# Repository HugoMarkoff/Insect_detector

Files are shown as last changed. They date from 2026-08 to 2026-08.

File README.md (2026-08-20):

# 🐞 Project Mariehøne

*“Mariehøne” is Danish for ladybug — which is exactly what the enclosure is.*





A wildlife-trap PCB repurposed into an **insect timelapse camera**, with a live
public gallery. An ATmega328P controller drives an infrared illuminator and a
Raspberry Pi + NoIR camera to take a frame every few minutes — no motion
trigger, just steady frames, day and night.

### ▶ Live gallery: **https://hugomarkoff.github.io/project-mariehoene/**

Built on the **Animal Detect Trap PCB V3.3** — ATmega328P +
Raspberry Pi + IMX708 NoIR camera, reverse-engineered from the Altium project
and the original Animal Detect firmware.

---

## What's here

| Path | What it is |
|---|---|
| **[docs/FLASHING.md](docs/FLASHING.md)** | **How to flash a board** — the two-stage procedure (one-time bootloader burn over ISP, then serial uploads), with a photo of exactly which pins to hold |
| [docs/HARDWARE.md](docs/HARDWARE.md) | Board reference: every connector pinout, the MCU pin map, power architecture, and the full I2C command table |
| [docs/RPI.md](docs/RPI.md) | The Raspberry Pi side: timelapse capture, the live web gallery, and how it publishes to GitHub Pages |
| [firmware/](firmware/) | PlatformIO project — the ATmega328P timelapse firmware (v0.2) |
| [programmer/](programmer/) | Turn a working board into an ISP programmer (ArduinoISP) + a retry-until-it-works bootloader burner |
| [rpi/](rpi/) | Raspberry Pi scripts: `timelapse.py` (capture + gallery), `gh_uploader.py` (push to GitHub), systemd units |
| [web/](web/) | The GitHub Pages gallery front-end (`index.html`) |

---

## How it works

The board can run in two modes; the firmware supports both.

**1. WiFi timelapse (what's deployed here)** — the Raspberry Pi stays powered and
runs the show:

```
Raspberry Pi (always on, WiFi)                 ATmega328P (I2C slave @0x08)
  every 3 min:                                   ┌───────────────────────┐
  ├─ I2C: IR on  (0x0F) ───────────────────────► │ drives IR illuminator │
  ├─ capture frame (NoIR camera)                 │ reads battery / light │
  ├─ I2C: IR off (0x0F) ───────────────────────► │ level-shifted 5V↔3V3  │
  ├─ save + serve local gallery (:8080)          └───────────────────────┘
  └─ git push rolling window ─► GitHub ─► Pages ─► public gallery
```

**2. Battery trap (low-power)** — the ATmega328P is the scheduler: it power-gates
the Pi, wakes it on an interval (or PIR/reed), lets it capture, then cuts power
and sleeps. Set always-on (`0x0E`) to keep the Pi up, or let it cycle to save
battery. See the command table in [docs/HARDWARE.md](docs/HARDWARE.md).

> ⚡ **On battery the Pi's 5 V is gated by the Arduino**, so without an always-on
> command the firmware will power-cycle the Pi every ~80 s by design. [docs/RPI.md](docs/RPI.md)
> explains the always-on setup that keeps it running for the WiFi timelapse.

---

## Quick start

1. **Flash the board** → [docs/FLASHING.md](docs/FLASHING.md). A fresh chip needs a
   one-time bootloader burn over ISP; after that it takes normal serial uploads.
2. **Build & upload the firmware:**
   ```bash
   cd firmware
   pio run -e Upload_UART -t upload      # over the Boot1 serial header
   ```
3. **Set up the Raspberry Pi** — clone this repo on the Pi and run the installer:
   ```bash
   cd project-mariehoene/rpi && GH_USER=<you> ./setup.sh
   ```
   It installs the capture loop, local gallery, and GitHub Pages publisher as
   systemd services, and walks you through the deploy key. Details in
   [docs/RPI.md](docs/RPI.md).
4. **Watch it** at your Pages URL, or locally at `http://<pi-ip>:8080/`.

Tuning (all in [firmware/src/main.cpp](firmware/src/main.cpp) or at runtime over I2C):

- Interval: `#define DEFAULT_INTERVAL_SECONDS`, or I2C `0x0D` (2 bytes of seconds).
- Quiet window: I2C `0x06` (from/to h,m,s) — skip captures at night.
- Bench testing without a battery: `#define ENABLE_BATTERY_GUARD 0` (a floating
  A0 reads garbage and would otherwise sleep the MCU forever).

---

## Hardware

Animal Detect Trap PCB V3.3 · ATmega328P @ 16 MHz · Raspberry Pi · IMX708 NoIR
camera · IR illuminator · 2S Li-ion. The board carries connectors for PIR, reed
(MAG), an IR/flash output, a spare trigger output, an LDR (dusk sensing), and a
`Boot1` serial header for programming. Full pinout in [docs/HARDWARE.md](docs/HARDWARE.md).

## Contributing

Issues and PRs welcome — see [CONTRIBUTING.md](CONTRIBUTING.md). Ideas and open
improvements are tracked in [docs/IMPROVEMENTS.md](docs/IMPROVEMENTS.md).

## License

[MIT](LICENSE) © 2026 Hugo Markoff.

## Credits

Derived from the Animal Detect trap platform. Firmware and the
RPi stack rewritten here for standalone insect timelapse use (no cloud backend —
images publish straight to GitHub Pages).

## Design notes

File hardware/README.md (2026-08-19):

# Open hardware — Animal Detect camera-trap family 🔓

The PCB designs and production 3D-print files behind the Really a Robot /
Animal Detect camera trap — the same hardware the [insect detector](../README.md)
is built from. Released open source under the repository's MIT license
(if you build or remix, a mention is appreciated).

## PCBs (Altium)

| Board | Newest ★ | Folder | What's inside |
|---|---|---|---|
| **IR array** (batwing illuminator) | v6.1 | `pcb/ir-array/` | v5 complete project (PrjPcb + SchDoc — the only schematic), v6 + **v6.1 ★** PcbDocs |
| **Main trap PCB** (ATmega328P host for a Pi Zero) | SMT2024 SMD-v3 | `pcb/trap-main/` | **SMD-v3 ★** complete project, early apr02 respin, v3.3 project + `full-archive-with-history.zip` (10 design snapshots V2→V3.2 **including manufacturing gerbers**) + `v3-docs/Trap_PCB_V3.pdf` |
| **PIR module** | v1.0 | `pcb/pir/` | PcbDoc + SchDoc |

Key dimensions, parsed straight from the PcbDocs:

| Board | Size | Mount holes |
|---|---|---|
| IR array v6.1 | 81.0 × 98.4 mm batwing, camera slot 37.2 wide | 2 × Ø3.0 on the centreline at (0,−6.5), (0,−29.1) |
| Main trap SMT2024 | 82.0 × 40.0 mm | 4 × Ø2.8 in a 58 × 23 pattern (= Pi Zero pattern — the Pi stacks on) |
| PIR v1.0 | 40.2 × 20.5 mm | 3 × Ø2.2 triangle: (−15, ±10) and (+15, 0) |

The magnet input is a bare reed switch on the trap PCB's MAG line — it never
had its own board.

## Camera-trap 3D parts (`cad/`)

The complete production print set (3MF), 30 files:

| Group | Parts |
|---|---|
| Enclosure | `Front-shell`, `Back-shell`, `Cam-Insert`, `IR-Insert-Folding`, `Bracket` |
| Battery | `Battery_Top`, `Battery_Buttom`, `Battery-Knob`, `BattPCB-Bracket` |
| Charger | `Charger-Top`, `Charger-buttom`, `Charger-IconInlay` |
| PIR | `PIRbracket`, `PIR-Funnel` (+ `TEST/New-PIR/` variants) |
| Antenna | `AntennaSafe`, `AntennaSafeInsert`, `AntennaSafeTip` |
| Mounting | `TreeBracket`, `Tree-Knob`, `Shade`, `Shade - Big` |
| `TEST/` | print-tuning coupons (`M3-test`, `PET-G_Test`, shell/PIR variants) |

`Cam-Insert` is worth a look even if you build nothing else: it encodes the
camera ↔ pogo-interface-board stack (camera in a 1.2 mm pocket, second board
7.4 mm seat-to-seat above it) that the insect detector's ladybug belly reuses.

## Bill of materials & docs (`docs/`, `pcb/trap-main/v3-docs/`)

| File | What |
|---|---|
| `docs/AD_BOM_list.xlsx` | AD camera bill of materials |
| `docs/Trap_v4_BOM.xls` | Trap v4 bill of materials |
| `pcb/trap-main/v3-docs/Trap_PCB_V3.pdf` | Trap PCB V3 documentation |
| `pcb/trap-main/v3-docs/Schematic_V3.jpg` | Trap V3 schematic (image) |
| `pcb/trap-main/v3-docs/i2c-Pogo-diagram-V2.jpg` | The I2C **pogo-pin interface** diagram |

## Legacy firmware & code

- `firmware-legacy/` — the original Arduino bring-up sketches: battery
  capacity (Li-Ion + NiMH), I2C tests, latch/battery-status tests.
- `legacy-camera-code/` — full snapshot of the original Bitbucket repo
  (`rmd_rar`): trap-PCB PlatformIO firmware + Raspberry Pi capture/upload
  scripts. **All credentials stripped** — see `LEGACY-NOTE.md` inside.

## Related

- The **ladybug insect-camera enclosure** (parametric FreeCAD) lives on the
  `main` branch under [`enclosure/`](../../tree/main/enclosure).
- Firmware for the trap PCB + Raspberry Pi timelapse/upload scripts:
  [`firmware/`](../../tree/main/firmware) and [`rpi/`](../../tree/main/rpi)
  on `main`.

## Notes

- Altium files are binary; folders are organised **one version per folder**
  so history stays browsable without Altium.
- No keys, credentials, or customer data are contained in any of these files.

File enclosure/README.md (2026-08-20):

# Ladybug enclosure 🐞 — v1.2

**v1.2:** ~20 % more floor area (body 142 × 188) and a properly hollow shell
(walls 3.0 / 2.6 mm) — real storage room under the dome. Every hardware mount
sits at the same coordinates as v1.1, so boards swap straight over.

A 3D-printed ladybug that hides the electronics under its shell and looks
**straight down** at whatever it's standing over. Legs are Lego-style stacking
blocks, so the same body works at 2 cm or 15 cm off the ground.

**Part 1 (here): the belly** — [`ladybug_belly.py`](ladybug_belly.py), a
parametric FreeCAD script. [`make_drawing.py`](make_drawing.py) generates a
dimensioned top/bottom drawing from the same parameters.
**Part 2 (also here): the domed elytra shell** — `build_shell()` in the same
script, so the seal dimensions can never drift apart.

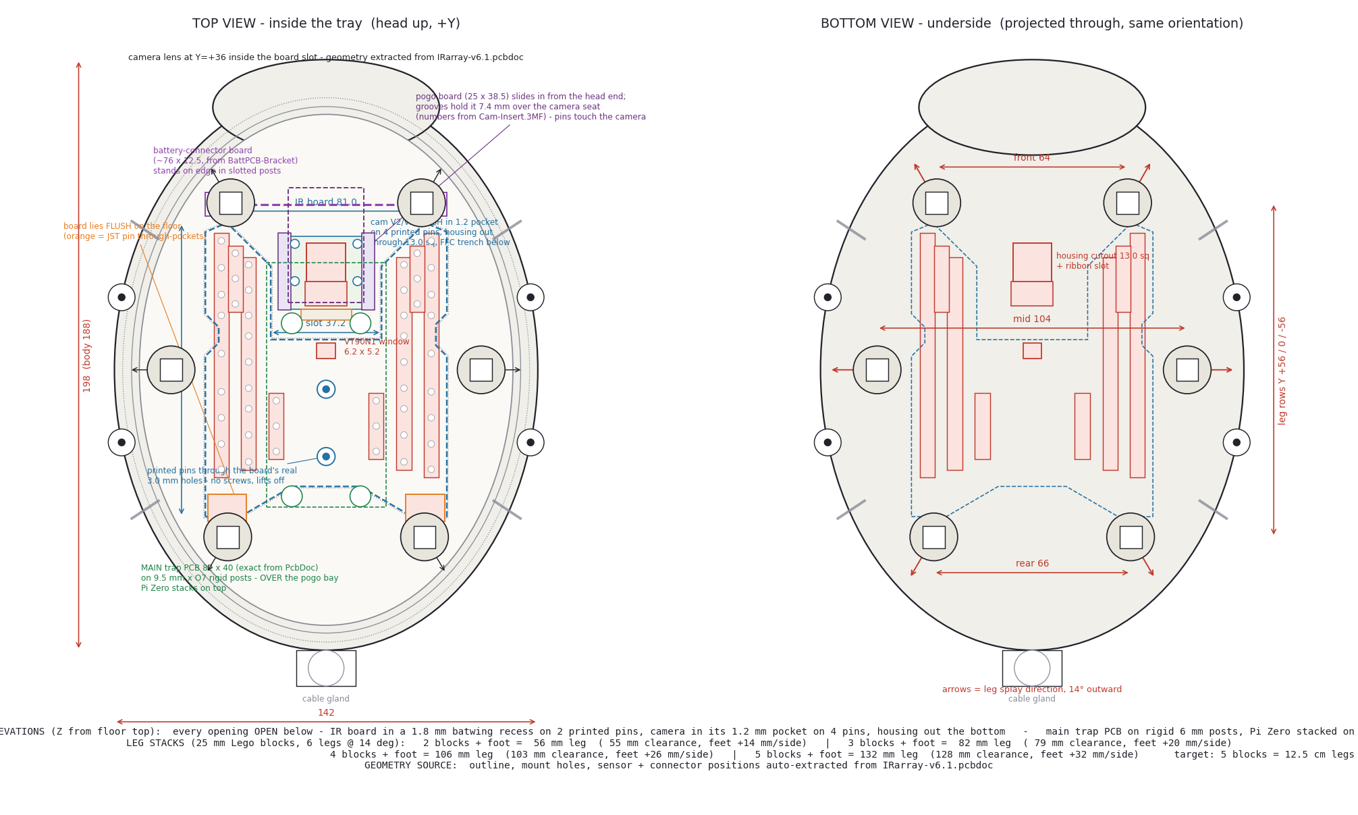
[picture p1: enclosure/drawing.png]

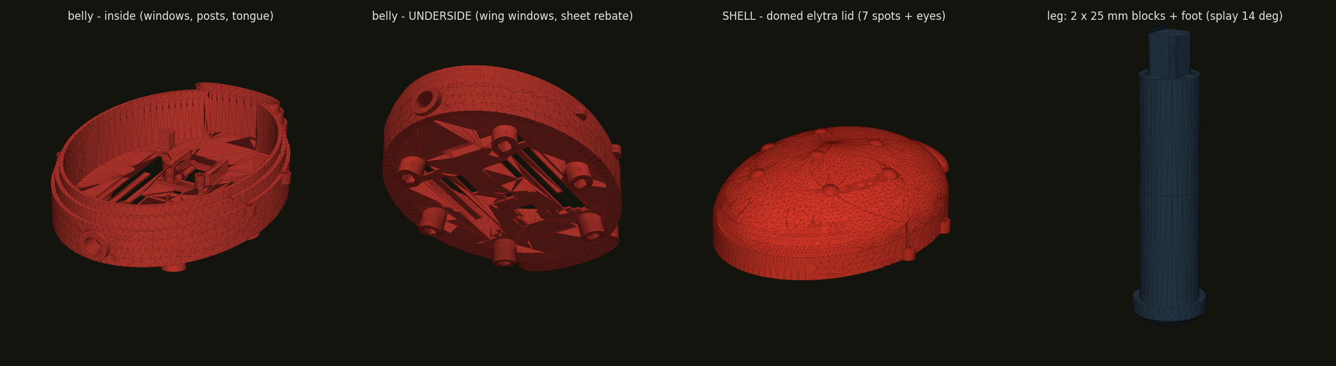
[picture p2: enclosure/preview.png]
preview


The IR board's geometry was pulled **straight out of the Altium file** (see
[`irboard_extracted.png`](irboard_extracted.png)) — outline, mount holes,
sensor and connector positions are manufacturing-exact.

## How the real hardware mounts

Everything lives **inside** the body. Measured off the actual boards:

| Part | Where it goes | How |
|---|---|---|
| **IR board** (batwing X, 81 × 98.4 — exact from the PcbDoc) | Drops into a **1.8 mm batwing recess** (~1 mm slack) onto **two printed pins** through its real holes (0,−6.5)/(0,−29.1) — no screws, lifts straight off | The floor has **one slot per LED column** (sized to the exact 48 LED positions from the PcbDoc; touching columns merge) — only the diode zones and the light sensor are open. The centre strip (logo, mount holes, the JST pins, the sensor legs) stays over solid floor, and the board **seals its own opening**: LEDs drop into the windows, the sensor into its hole, the JST pin fields into through-pockets. Silicone/foam on the strip makes it airtight |
| **Light sensor** (VT90N1 at (0,+6.3) — from the PcbDoc) | Its own **rectangular window (6.2 × 5.2)** matching the CdS cell's body | Reads ambient light straight down |
| **Camera** (Pi V2 **or** V3 — same 25 × 24 board, 21 × 12.5 holes) | **Flush in a 1.2 mm floor pocket** inside the board slot, located by **four printed pins** (Ø1.8 in its 2.2 mm holes) | Only the **sensor housing pokes out** through a 13 mm square cutout (passes the bulky Module 3 housing), with a wide offset slot that swallows both the V3 ribbon and V2's L-shaped flex; a shallow trench lets the main FFC cable lie flat. Above it, **slide-in rails carry the pogo interface board** (25 × 38.5) exactly 7.4 mm over the camera seat — spacing decoded from `Cam-Insert.3MF` — so the pogo pins land on the camera's back |
| **Main trap PCB** (82 × 40, holes 58 × 23 — exact from its PcbDoc) | Across the body on rigid 9.5 mm × Ø7 posts, riding just above the pogo board | Upper posts stand in the camera slot, lower ones below the board's bottom edge; the **Pi Zero stacks onto the trap PCB's own 58 × 23 pattern** |

> **Sealing:** there is **no window sheet** — every opening is filled by the
> component that uses it, and the boards clamped flush **are** the seal. The
> openings face the ground, so rain can't fall in. Conformal-coat the IR
> board's LED face (or spray it with clear lacquer) for damp nights.

The board keeps **~1.5–6 mm wiggle room** to the cavity wall all the way round —
it drops in flat and lifts out without a fight.

## Build it

FreeCAD 1.0+ (free). Either open the script in FreeCAD's Python console, or run
it headless — it writes STLs into `stl/` and a `ladybug.FCStd` you can open and
edit:

```bash
"C:\Program Files\FreeCAD 1.0\bin\FreeCADCmd.exe" ladybug_belly.py
```

It prints a check per part; every one must say `printable=True` (a single closed
solid). Current output:

Every run builds **both size options** — same features, shared legs:

| Part | v1.1 (1:1 original) | v1.2 (+20% floor) |
|---|---|---|
| `belly` | 135 × 185 × 54 mm, ~174 cm³ → `stl/v1.1/` | 146 × 201 × 54 mm, ~195 cm³ → `stl/v1.2/` |
| `shell` | 136 × 186 × 59 mm, ~137 cm³ → `stl/v1.1/` | 148 × 202 × 59 mm, ~154 cm³ → `stl/v1.2/` |

Both shells are the hollow thin-wall design; legs below fit either body.

| Shared part | Size | Volume |
|---|---|---|
| `leg_segment` | Ø13 × 35 mm (25 body + 10 peg) | 3.1 cm³ |
| `leg_segment_half` | Ø13 × 22.5 mm | 1.5 cm³ |
| `foot` | Ø16 collar + ball, 16.5 mm | 1.4 cm³ |

## The waterproof lid ("lift") — how the seal works

The shell is a **lid that lifts straight off**. Water never gets a straight path
in, because the joint is a labyrinth:

```
        shell skirt (part 2)
          |  ||                  skirt hangs OUTSIDE, down over the rebate
          |  ||   __ tongue      belly tongue rises INSIDE the skirt,
          |  ||  |  |            into a matching groove in the shell
       ___|  ||__|  |___         seat + gutter, with weep notches
      |      belly       |
       \__ shoulder: skirt edge stops here, water drips off __/
```

- Rain runs down the shell and **drips off the skirt's bottom edge** at the
  shoulder — below and outside the joint.
- To get in, water would have to climb **8 mm up a gap and over a 6 mm tongue**.
  It can't; gravity is on our side.
- Any splash that does land in the gutter drains out through the **weep
  notches** cut in the top of the rebate wall.
- The **screw ears are outside the seal**, so the fixings can't leak.
- The **leg sockets are blind** — they open downward only and never break
  through the floor into the dry side.

Two things you still add by hand:

1. **The gasket.** Run a thin bead of silicone (or lay 1 mm foam tape) on
   the floor's centre strip and around the camera pocket before pressing the
   boards down — PCB on plastic is weather-resistant, silicone makes it
   airtight (and still peels open for service).
2. **A vent.** A fully sealed box breathes with temperature and sucks moisture
   past any seal. Stick a small square of PTFE/Gore vent tape over a 3 mm hole
   drilled high on a side wall, or accept the (slightly leaky) cable gland as
   your vent.

## Printing

| Part | Qty | Notes |
|---|---|---|
| `belly` | 1 | Print as-is, belly down. The leg bosses are the only overhang and they're short — no supports needed. |
| `shell` | 1 | Print as modelled (skirt ring down). The dome is self-supporting; the groove bridges are ~3 mm — fine. Red filament, black spots with a marker (or pause-and-swap). |
| `leg_segment` | 30 (6 legs × 5) | 25 mm each — 5 per leg ≈ 12.5 cm legs. |
| `leg_segment_half` | 4–8 | 12.5 mm fine-adjust blocks for slopes. |
| `foot` | 6 | Print peg-up. |

0.2 mm layers, 3 perimeters, 20–30 % infill. **PETG or ASA if it lives
outdoors** — PLA sags in a sun-baked enclosure. TPU feet grip better and damp
vibration.

> **Print one `leg_segment` + one `foot` first** and check the peg grip. Too
> loose → lower `fit` (0.15–0.2). Too tight → raise it (0.4–0.5). Printer
> tolerance varies more than the model does; this one number is the whole trick.

## Height adjustment (the Lego bit)

**Six legs — front, middle and rear pairs — tilted 14° outward** like a
tripod. The system is LEGO-simple: **round parts outside (Ø13 blocks, Ø16
belly bosses, Ø16 ball feet), ONE standard square hole inside** — a straight
7.15 mm peg in a 7.45 mm rounded-corner socket — 0.3 mm of wiggle: drops
together by hand, no slop. (The peg also fits bellies printed with the older
7.4 sockets, at 0.25 play.) The foot's top is a straight collar at exactly
`socket_od`, so the joint reads as one continuous column — if your printed
belly's bosses measure differently, set `socket_od` and reprint only the feet. 10 mm engagement + blocks butting face-to-face keep tall stacks
stiff instead of wobbling up. The belly sockets are angled,
so the taller you stack, the wider the stance. Every `leg_segment` adds **25 mm**
along the leg:

```
belly socket (14° out) → [block] → [block] → ... → [foot]
```

| Blocks per leg | Leg length | Ground clearance | Feet spread |
|---|---|---|---|
| 2 | 56 mm | 54 mm | +14 mm/side |
| 3 | 81 mm | 79 mm | +20 mm/side |
| 4 | 106 mm | 103 mm | +26 mm/side |
| **5** | **131 mm ≈ 12.5 cm** | **127 mm** | **+32 mm/side** |

- **Square pegs** mean the legs can't rotate — the splay angle stays put.
- **Why 14°?** The camera sees ~62° × 49°, so no sane splay keeps legs out
  of the extreme corners at every height — 14° keeps the upper leg sections
  (the close, blurry, dominant ones) out of view at working heights without
  making the stance silly. If you build very tall and the corners bother you,
  raise `leg_splay` a few degrees and reprint just the belly.
- Stack the downhill legs taller (use the half blocks) to stand level on a slope.

**Camera height is your focus knob.** The IMX708 won't focus closer than ~10 cm,
so print enough segments to bracket 10–20 cm.

## Fitting your hardware

Everything is in the `PARAMS` block at the top of the script — change a number,
re-run. The ones you'll actually touch:

| Param | What it does |
|---|---|
| `body_len`, `body_wid` | Overall footprint |
| `ir_outline` | The exact batwing outline (auto-extracted from `IRarray-v6.1.pcbdoc`) |
| `ir_mounts`, `sensor_pos` | Exact centreline holes + VT90N1 spot (from the PcbDoc) |
| `win_inset`, `win_xmin` | Wing-window fit: rim width and solid-strip width |
| `cam_pos`, `cam_lens_d` | Camera lens hole (Ø12 clears V2 and V3) |
| `cam_cut_sq`, `cam_fit` | Camera housing cutout + pocket tightness |
| `main_posts`, `main_post_h` | Trap-PCB standoffs (58 × 23 pattern, from its PcbDoc) |
| `leg_splay`, `leg_seg_h` | Tripod angle and block height |
| `fit` | Leg peg tightness |
| `skirt_th`, `skirt_gap`, `tongue_w`, `tongue_h` | The seal — part 2 must match these |

> ⚠️ Before printing the belly, measure and set: `ir_mounts` (the two
> centreline holes), `sensor_pos`, and check the notch/outline against your
> PCB. Everything else is dimensioned from the real hardware.
> The legs are safe to print right now.

### Internal layout (bottom → top)

| Z from floor top | What |
|---|---|
| 0–3 mm | Floor, with wing windows + sensor + lens holes; clear sheet in the rebate below |
| 3 mm | Camera posts — lens reaches down into its hole, baffle collar around it |
| below 0 | Camera **sensor housing pokes out** (V2 ~2.5 mm, V3 ~5 mm); LED domes sit just inside their windows |
| 0–3 mm | Floor — **IR board and camera both recessed flush on printed pins**, sealing their own openings |
| 13 mm | **Main trap PCB** on 10 mm posts; the Pi Zero stacks onto it above |
| 33 mm | Seat level — the shell's skirt lands here |

## Still to design

- [x] The domed **elytra shell** — seven-spot dome with eye bumps, skirt +
      groove matched to the belly, four M3 tabs over the belly ears.
      (The centre split line defeated the CAD kernel — draw it with a marker.)
- [ ] Lens hood / dew shield around the camera port.
- [ ] Head with the "eyes" as vent detail.

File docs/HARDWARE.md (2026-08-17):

# Trap PCB V3.3 — hardware reference

Reverse-engineered from `Trap_PCB_V3.3.SchDoc` (net-traced programmatically) and
the assembled board. Note: the schematic in the project folder lags the fabbed
V3.3 in component *packages* (it draws a DIP ATmega328-PU and an LM2576 buck;
the board carries a TQFP-32 MEGA328P-AU and an RT7272B buck) — but the **net
topology matches the firmware pin usage exactly**, so the pinouts below are the
fabbed board's.

## Power

- `VIN` JST (2-pin): 2S battery, ~6.0–8.8 V. Reverse diodes 1N5406, big input electrolytic.
- Buck regulator → **5.1 V rail**: MCU (AVCC/AREF too — that's why the firmware
  uses `analogReference(EXTERNAL)` with 5.0 as reference constant), sensors, and
  the switched RPi supply.
- Battery sense: A0 through 30K/7K5 divider (matches `R1=30000, R2=7500` in firmware).
- RPi power is **high-side switched by an IRLZ44N** driven from `A2-GATE`
  (Arduino pin 16 / A2, `RELAY_PIN` in firmware). Two more IRLZ44Ns low-side
  switch the `Trig` and `IR` JST loads (gates on D4 / D5).

## MCU pin map (ATmega328P, Arduino numbering)

| Arduino | Net | Function |
|---|---|---|
| D0/D1 | RX / TX | Serial: debug + urclock upload (Boot1 header) |
| D2 | D2-PIR | PIR signal (INT0) |
| D3 | D3-MAG | Reed/magnet sensor (INT1) |
| D4 | D4-Trig | Low-side switch for `Trig` JST |
| D5 | D5-IR | Low-side switch for `IR` JST (IR flash board) |
| D10 | CS | Digipot chip-select (digipot sits on the PIR sensor board) |
| D11 (MOSI) | SI | Digipot data — also on PIR connector pin 6 |
| D12 (MISO) | MISO | **Chip leg only — no connector.** Needed for ISP |
| D13 (SCK) | SCK + D13-LED | Digipot clock, PIR pin 5, onboard LED (220R) |
| A0 | A0-BATT | Battery divider |
| A1 | A1-LDR | Photoresistor (`LDR` JST) — dusk detection for IR flash |
| A2 (D16) | A2-GATE | RPi power gate (firmware `RELAY_PIN`) |
| A4/A5 | SDA/SCL | I2C slave @ 0x08 to the RPi, level-shifted by 2N7000 pair |
| RESET | Reset | 10K pull-up, RST button to GND, 100 nF from Boot1 DTR |
| XTAL | Crystal1/2 | 16 MHz + 22 pF |

## Connectors

### Boot1 — programming/serial header (6-pin 2.5 mm female, bottom-right)

| Pin | Net |
|---|---|
| 1 | DTR (cap-coupled to RESET) |
| 2 | TX |
| 3 | RX |
| 4 | 5.1V |
| 5 | GND |
| 6 | NC |

### PIR Sensor (JST-PH 2.0 mm, 6-pin)

| Pin | Net | Note |
|---|---|---|
| 1 | 5.1V | |
| 2 | GND | |
| 3 | D2-PIR | Motion signal |
| 4 | CS | Digipot (sensitivity) on sensor board |
| 5 | SCK | **ISP tap point** |
| 6 | SI (=MOSI) | **ISP tap point** |

### Small JSTs

| Conn | Pin 1 | Pin 2 |
|---|---|---|
| VIN | Battery + (VIN net) | GND |
| Trig | 5.1V | switched drain (low-side FET, D4) |
| IR | 5.1V | switched drain (low-side FET, D5) |
| LDR | A1 divider | (photoresistor) |
| MAG | GND / 5V / SIG(D3) | 3-wire sensor |

### Pogo pins P1–P7 (press onto the RPi Zero 2 W header holes 1–6 + GND)

| Pogo | Net | RPi header pin |
|---|---|---|
| P4 | POGO-3V | 1 (3V3 — used only as level-shifter reference) |
| P1, P2 | 5.1V (switched) | 2, 4 (5V in) |
| P5 | POGO-SDA | 3 |
| P6 | POGO-SCL | 5 |
| P3, P7 | POGO-GND | 6, 9 |

The 2N7000 pair shifts SDA/SCL between the AVR's 5 V and the RPi's 3.3 V using
POGO-3V as the low-side pull-up rail — the classic bidirectional MOSFET shifter.

## I2C protocol (Arduino = slave @ 0x08, firmware v0.2)

**Writes** (`i2cset -y 1 0x08 CMD data…`):

| Cmd | Payload | Meaning |
|---|---|---|
| 0x00 | s, m, h | Sync wall clock |
| 0x04 | hours | Ping interval |
| 0x05 | h, m, s | Ping time |
| 0x06 | from h,m,s + to h,m,s | Quiet window (no captures inside it) |
| 0x08 | seconds | IR flash on (respects dusk value) |
| 0x09 | value/4 | Dusk threshold |
| 0x0B | 1–254 | PIR sensitivity (digipot) |
| 0x0C | minutes (254=default) | Capture interval, coarse |
| 0x0D | hi, lo (seconds, ≥15) | **Capture interval in seconds** |
| 0x0E | 0/1 | **Always-on: 1 = never cut RPi power on timeout** |
| 0x0F | pin, state | **Direct output write: 0=IR, 1=Trig, 2=RPi gate** |
| 0x15 | seconds (10–255) | RPi on-time budget per cycle (default 80) |

**Reads** (`i2cset -y 1 0x08 CMD` then `i2cget -y 1 0x08`, or smbus write+read):

| Cmd | Returns |
|---|---|
| 0x01 | Setup status (0 = fresh boot, wants full config) |
| 0x02 | Battery % |
| 0x03 | Trigger reason: 1 PIR, 2 ping, 3 reed, **4 timelapse** |
| 0x07 | (Request shutdown — Arduino cuts RPi power after this) |
| 0x0A | Image type (0 RGB, 1 IR) |
| 0x10 | **PIR input level** |
| 0x11 | **Reed/MAG input level** |
| 0x12 | **LDR reading /4 (0–255)** |
| 0x13 | **Battery voltage in decivolts (74 = 7.4 V)** |
| 0x14 | **Firmware version (2)** |

Cadence math: the capture schedule anchors at cycle start —
`next = cycle_start + interval` — so RPi boot/capture/shutdown time is absorbed
into the sleep and shot-to-shot spacing equals the configured interval exactly
(as long as interval > cycle time, i.e. ≥ ~60 s intervals are safe with a 45 s cycle).

Always-on: send `0x0E 0x01` at boot and simply never send `0x07` — the Arduino
freezes its timeout clock and leaves power up indefinitely. An explicit `0x07`
still shuts down even in always-on. Direct gate control (`0x0F 0x02 0x00`)
cuts your own power — that's the intended way for the RPi to hard-poweroff
outside the normal handshake (run `sudo poweroff` first, gate off ~10 s later
via a shutdown service, or just let cmd 0x07 handle it).

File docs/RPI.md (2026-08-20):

# Raspberry Pi setup — capture, gallery & publishing

The Pi runs three moving parts, all as systemd services so they survive reboots
(important on battery, where the board can brown-out and restart):

1. **`timelapse.py`** — captures a frame every N seconds, drives the IR output on
   the Arduino around each shot, and serves a live local gallery on `:8080`.
2. **`gh_uploader.py`** — pushes the newest frames to GitHub as a rolling window.
3. **GitHub Pages** — serves the public gallery from the pushed images.

```
timelapse.py ──► ~/timelapse_images/*.jpg ──► gh_uploader.py ──► GitHub (images branch)
      │                                                                    │
   :8080 local gallery                          gh-pages branch (index.html) + GitHub Pages
                                                                           │
                                                          public gallery (auto-refreshes)
```

## Files

| File | Role |
|---|---|
| [rpi/timelapse.py](../rpi/timelapse.py) | Capture loop + local web gallery |
| [rpi/gh_uploader.py](../rpi/gh_uploader.py) | Rolling-window push to GitHub over an SSH deploy key |
| [rpi/insect-timelapse.service](../rpi/insect-timelapse.service) | systemd unit for capture (sets Arduino always-on on start) |
| [rpi/insect-uploader.service](../rpi/insect-uploader.service) | systemd unit for the GitHub push |
| [rpi/rc.local](../rpi/rc.local) | Neutralised boot script (replaces the old Firebase autostart) |
| [web/index.html](../web/index.html) | The Pages front-end (lists images via the GitHub API) |

## Capture (`timelapse.py`)

Configurable entirely by environment variables (set in the service unit):

| Env | Default | Meaning |
|---|---|---|
| `TIMELAPSE_INTERVAL` | `180` | Seconds between captures |
| `TIMELAPSE_IR_HOLD` | `0` | `1` = force the IR output on continuously (hardware test) |
| `TIMELAPSE_DIR` | `~/timelapse_images` | Where frames are written |

Each cycle: assert IR on (I2C `0x0F`), capture with `rpicam-still` (NoIR tuning),
IR off, save a timestamped JPEG, sleep to the next slot. It also sends the
Arduino **always-on** (`0x0E`) on startup so the board doesn't power-cycle the Pi.

Browse the raw feed locally at `http://<pi-ip>:8080/`.

## Insect detection (`detect.py`)

Each new frame is compared to the previous one (downscaled, blurred grayscale
absolute difference). A small, **localized** change means something appeared on
the otherwise-static scene — flagged as a likely insect. A near-zero change is an
empty frame; a huge change is a light/camera shift and is ignored. Thresholds are
env-tunable (`DETECT_DIFF`, `DETECT_MIN_FRAC`, `DETECT_MAX_FRAC`). It's a motion
proxy, not an ML classifier (see [IMPROVEMENTS.md](IMPROVEMENTS.md)); needs Pillow.

## Publishing (`gh_uploader.py`)

Keeps only the last `GH_KEEP` (default 60) images and **force-pushes a single
squashed commit** to the `images` branch — so repo history never grows and the
Pages branch is never rebuilt. It also writes **`manifest.json`** (each frame +
its insect flag/score, newest-first), which the gallery reads as its single data
source — one request per refresh instead of a directory crawl. The gallery shows
a **timelapse player** (plays frames across time), the **last 10 frames**, and the
**last 10 flagged with insects**.

Auth is an **SSH deploy key** scoped to this one repo (`~/.ssh/insectcam_deploy`),
not a token. The repo must be **public** for anonymous visitors' browsers to read
the image list.

## First-time setup

**The easy way** — clone the repo on the Pi and run the installer, which does
everything below (deps, deploy key, gh-pages, services) and only asks you to
paste one public key:

```bash
cd project-mariehoene/rpi && GH_USER=<your-github-user> ./setup.sh
```

<details><summary>Or do it manually</summary>

```bash
# 1. Dependencies
sudo apt-get update && sudo apt-get install -y git python3-smbus2   # (smbus2 via pip if unavailable)

# 2. Deploy key (grant the Pi push access to just this repo)
ssh-keygen -t ed25519 -N '' -f ~/.ssh/insectcam_deploy -C insectcam-pi
cat ~/.ssh/insectcam_deploy.pub
#   → add at github.com/<you>/project-mariehoene/settings/keys  (✅ Allow write access)

# 3. Copy scripts to ~/ , then install the services
sudo cp insect-timelapse.service insect-uploader.service /etc/systemd/system/
sudo cp rc.local /etc/rc.local && sudo chmod +x /etc/rc.local   # removes old Firebase autostart
sudo systemctl daemon-reload
sudo systemctl enable --now insect-timelapse.service insect-uploader.service

# 4. Gallery front-end → push web/index.html to a gh-pages branch, then enable
#    GitHub Pages (Settings → Pages → gh-pages / root). Repo must be public.
```

</details>

## Changing settings

```bash
# capture interval → edit TIMELAPSE_INTERVAL in the unit, then:
sudo systemctl daemon-reload && sudo systemctl restart insect-timelapse

# watch logs
journalctl -u insect-timelapse -f
journalctl -u insect-uploader -f
```

## Troubleshooting

| Symptom | Likely cause / fix |
|---|---|
| Pi reboots every ~80 s on battery | Arduino gate timeout — the always-on command isn't reaching it. Confirm `insect-timelapse.service` runs on boot (it sends `0x0E`). |
| Gallery page loads but is empty | Repo is **private** — GitHub blocks anonymous API access. Make the repo public. |
| `git: command not found` | `sudo apt-get install -y git` |
| Uploader `push failed` | Deploy key missing write access, or not added to the repo. Re-check `ssh -i ~/.ssh/insectcam_deploy -T git@github.com`. |
| Camera busy / capture fails | A stray `rpicam-still` is holding the device: `pkill -f rpicam-still`. |

> The old Animal Detect Firebase flow (`camera.sh` + `main.py` via `/etc/rc.local`)
> is intentionally disabled here. A backup of the original rc.local is kept at
> `/etc/rc.local.firebase.bak` on the Pi.

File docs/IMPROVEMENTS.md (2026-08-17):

# Improvements & roadmap

A living list of where this project can get better. Good first issues are marked
🟢. Contributions welcome — see [CONTRIBUTING.md](../CONTRIBUTING.md).

## ✅ Fixed in the pre-release hardening pass

An automated code review + fixes landed these:

- **I2C ISR no longer does Serial/`analogRead`.** The firmware's `receiveEvent`/
  `requestEvent` run in interrupt context; they now only latch bytes and return
  values cached by the main loop (`sampleSensors()`), removing a real
  bus-stall / potential deadlock that hit on every capture.
- **Capture directory is bounded.** `timelapse.py` prunes `~/timelapse_images`
  to the newest `TIMELAPSE_MAX_STORED` (500) frames — no more silent SD fill.
- **Battery guard is recoverable + bench-safe.** Requires two consecutive
  out-of-range readings before shutdown, and `ENABLE_BATTERY_GUARD` defaults to
  `0` (a floating A0 was bricking fresh bench builds).
- **SMBus fd leak fixed** (`with smbus2.SMBus(1)`), and the uploader no longer
  crash-loops on a git error (`ensure_repo` retries inside the loop).
- **Explicit gate-off honored.** `0x0F` pin 2 → 0 now actually cuts RPi power
  (was defeated by the capture loop re-asserting the pin).
- **Truncated-frame guard** in the uploader (re-copies if the source grew),
  `volatile` on ISR-shared globals, `LED_PIN` pinMode, atomic time reads, and
  the Windows-only burn tool no longer crashes on import on Linux/macOS.

## P1 — still open

- [ ] **Use the watchdog.** `avr/wdt.h` is included but unused; a watchdog reset
      would recover the MCU from any hang in the field.
- [ ] **Wall-clock sync for the ping/quiet paths.** `timelapse.py` never sends
      `CMD_TIME`, so the firmware clock free-runs — fine today (those paths are
      inactive) but the quiet-window feature needs it. Send `0x00` periodically
      if you enable quiet hours. 🟢

## P2 — robustness / quality

- [ ] **Uploader backoff.** Add exponential backoff on repeated push failures
      instead of retrying every cycle during an outage.
- [ ] **Gallery API rate limit.** The Pages front-end polls the GitHub API
      (60 req/hr per anonymous IP). For many simultaneous viewers, publish a
      small `manifest.json` alongside the images and read that instead.
- [ ] **Timestamp overlay** burned into each frame (date/time, battery %).
- [ ] **`volatile` for multi-byte ISR state.** `updateTimeStruct` / `pingTime` /
      `ignoreTime*` are written in the I2C ISR and read in `loop()`; guard those
      reads with `ATOMIC_BLOCK` if you enable the ping/PIR paths.

## P3 — features

- [x] **Change detection** ([rpi/detect.py](../rpi/detect.py)) flags frames with a
      small, localized change ("likely insect") into `manifest.json`; the gallery
      has a dedicated insect view + a timelapse player. It's a motion proxy on the
      static scene — a **trained insect classifier** is the next step up.
- [ ] **Daily timelapse video** — an `ffmpeg` job stitching each day's frames.
- [ ] **On-device storage fallback** — keep capturing when WiFi is down.
- [ ] **Focus-stacking / macro optics** notes and mounts for sharp insect shots.
- [ ] **Power budget** — measure sleep current and per-shot Wh for the low-power
      trap mode.

## Portability (for forks)

- [x] `rpi/setup.sh` generates the systemd units + templates the front-end from
      `GH_USER`/`GH_REPO`/`INTERVAL` — a fork edits nothing by hand.
- [x] Camera tuning path is now `TIMELAPSE_TUNING` (env), with graceful fallback.
- [x] The uploader warns when `GH_OWNER` is unset instead of silently pushing to
      the author's repo.
- [ ] Collect the remaining fixed assumptions (`I2C addr 0x08`, bus `1`, camera
      rotation `180`) into one documented config block.

## Infrastructure

- [x] MIT license, `CONTRIBUTING.md`, and CI that compiles the firmware on every
      push/PR (`.github/workflows/firmware.yml`).
- [ ] Basic unit tests for the Python (filename parsing, rolling-window logic).

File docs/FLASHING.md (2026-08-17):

# Flashing the Trap PCB V3.3 (ATmega328P)

Reconstructed from the Altium schematic (`Trap_PCB_V3.3.SchDoc`) and the original
`platformio.ini` of the Animal Detect arduino-controller repo. This is the
procedure you half-remembered: **the DTR header is for everyday uploads, but a
factory-fresh ATmega328P is completely blank, so once per board you must burn
the bootloader over ISP — and this PCB has no ISP header, so two of the six ISP
signals have to be held directly against pins.**

## The two stages

| Stage | When | Interface | Command |
|---|---|---|---|
| 1. Burn fuses + urboot bootloader | **Once per fresh chip** | ISP (SPI) via USBasp + held wires | `pio run -e fuses_bootloader -t bootloader` |
| 2. Upload sketches | Every code change | `Boot1` 6-pin serial header (DTR auto-reset, urclock @ 115200) | `pio run -e Upload_UART -t upload` |

Fuse config burned in stage 1 (from the original project): external 16 MHz
crystal, BOD 2.7 V, EEPROM preserved, **urboot** bootloader on UART0 @ 115200.

---

## Stage 1 — bootloader over ISP (the "holding cables on pins" part)

ISP needs 6 signals: VCC, GND, RESET, SCK, MOSI, MISO. On this board they are
scattered — the PIR connector happens to carry the SPI bus (it drives the
digital potentiometer on the PIR sensor board), but **MISO reaches no connector
at all**:

| ISP signal | Where on the board | Notes |
|---|---|---|
| VCC (5V) | **PIR connector pin 1** (5.1V) | Only feed 5 V if **no battery** is on VIN. With a battery attached, leave programmer VCC disconnected (USBasp: remove the self-supply jumper). Boot1 pin 4 is the same net |
| GND | **PIR connector pin 2** | Boot1 pin 5 is the same net |
| SCK | **PIR connector pin 5** (`SCK`) | JST-PH 2.0 mm, 6-pin |
| MOSI | **PIR connector pin 6** (`SI`) | ditto |
| RESET | **Held/clipped: reset button leg** — the pair that is **not** continuous with GND (or TQFP pin 29) | Held wire #1. The Reset net has a 10K pull-up to 5.1V |
| MISO | **Held directly on the chip: TQFP-32 pin 16 (PB4)** | Held wire #2. No pad, no connector anywhere |

So the historical procedure was: a PH-6 pigtail (or dupont wires) into the PIR
connector for power + SCK + MOSI, plus **two hand-held wires** — MISO on the
chip leg and RESET on the button leg — for the ~20 s the burn takes.

### Finding MISO without counting pins

MISO sits at a package corner directly between the two legs you can identify by
continuity beep:

1. Beep from **PIR pin 6 (SI)** → finds TQFP pin 15 (MOSI), last-but-one leg on one side.
2. Beep from **PIR pin 5 (SCK)** → finds TQFP pin 17, first leg around the corner
   (it also connects to the onboard LED resistor — the LED lives on the SCK net).
3. **MISO = TQFP pin 16 = the single corner leg between those two.**

Hold a jumper-wire tip (or a pogo pin, or tack-solder a thin wire) on it for the
~20 s the burn takes. That plus the RESET clip is the "1–2 cables held on pins"
you remembered.

### USBasp 10-pin IDC pinout (for reference)

```
 1 MOSI   2 VCC
 3 NC     4 GND
 5 RESET  6 GND
 7 SCK    8 GND
 9 MISO  10 GND
```

### Run it

```bash
cd firmware
pio run -e fuses_bootloader -t bootloader
```

- Windows USBasp driver: install with **Zadig** → select "USBasp" → libusbK.
- The env already passes `-B8` (slow SPI clock) — required because a fresh chip
  runs at 1 MHz internal clock until the external-crystal fuse is set.
- If it can't sync: re-seat the MISO wire (most common), check RESET actually
  pulls to 0 V, try `-B32`.
- No USBasp? Use an Arduino Uno running the ArduinoISP example sketch and the
  `fuses_bootloader_arduinoisp` env in `platformio.ini` (same wiring, Uno pins
  10→RESET, 11→MOSI, 12→MISO, 13→SCK).

Success looks like avrdude writing lfuse/hfuse/efuse and flashing `urboot` with
verification OK. From this moment the chip has a bootloader forever (EESAVE +
serial uploads never erase it).

---

## Stage 2 — everyday uploads via `Boot1` (the DTR header)

The black 6-pin, 2.5 mm female header (bottom-right, next to the RST button) is
called `Boot1` in the schematic. Wire any 5 V USB-serial adapter
(FT232 / CP2102 / CH340 with a DTR pin):

| Boot1 pin | Net | USB-serial adapter |
|---|---|---|
| 1 | DTR | DTR (→ 100 nF cap → RESET auto-reset) |
| 2 | TX (board transmits) | RXD |
| 3 | RX (board receives) | TXD |
| 4 | 5.1V | 5V — only when not battery-powered |
| 5 | GND | GND |
| 6 | NC | — |

**Which physical end is pin 1?** Beep test once and mark the header with a
paint dot: the pin continuous with battery-minus / the electrolytic caps'
negative side is GND (pin 5); its direct neighbour is 5.1V (pin 4); the far end
is then DTR (pin 1). (Expect pin 1 to be the end nearest the `DTR` silk label.)

```bash
cd firmware
pio run -e Upload_UART -t upload      # urclock protocol @ 115200
pio device monitor -b 9600            # debug output
```

The original config hardcoded a macOS port (`/dev/cu.usbserial*`); the version
in this repo autodetects. If autodetection grabs the wrong port, uncomment
`upload_port = COMx` (see Device Manager → Ports).

If the upload retries without syncing: TX/RX swapped is the usual suspect; next
suspect is DTR not reaching reset — press the RST button just as avrdude starts
connecting as a manual fallback.

---

## Troubleshooting quick table

| Symptom | Cause → fix |
|---|---|
| ISP: `target doesn't answer` / `initialization failed` | MISO wire contact (hold steadier / tack-solder), RESET not held low, no power → check 5 V on Boot1 pin 4 |
| ISP: `cannot find USB device "USBasp"` | Driver → Zadig, libusbK |
| ISP works but chip later runs at wrong speed | Fuses not burned (you flashed only) → rerun the `-t bootloader` target, it sets fuses first |
| Serial upload: `urclock_recv(): programmer is not responding` | Wrong COM port, TX/RX swapped, DTR not wired, board unpowered, or stage 1 never happened |
| Serial monitor shows garbage | Baud mismatch — monitor is 9600, bootloader is 115200 (different things, both correct) |
| Board "dead" on the bench, no serial output | Battery guard put it to sleep (floating A0) → `ENABLE_BATTERY_GUARD 0` for bench work |

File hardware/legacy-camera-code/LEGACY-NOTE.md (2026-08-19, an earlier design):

# Legacy camera code (archived)

Snapshot of the original Animal Detect camera repo, archived here from
`bitbucket.org/hugo_markoff/rmd_rar` (last commit: `73fb3eb` — "Reduced time
and improved sensitivity code").

- `ArduinoCode/TrapCode/` — PlatformIO project for the ATmega328P on the trap
  PCB (the ancestor of the firmware on `main`'s `firmware/`).
- `RPiCode/` — the Raspberry Pi side: capture (`main.py`, `camera.sh`),
  Firebase upload, setup scripts.

**Credentials removed:** the original repo contained a Firebase service
account (`trapapp-…-adminsdk-….json`). It has been stripped from this
archive. The code still references it by filename — to run the Firebase
parts, supply your **own** service-account JSON at the path the scripts
expect. Never commit that file.

Archived for preservation; the maintained insect-camera code lives on the
`main` branch (`firmware/`, `rpi/`).

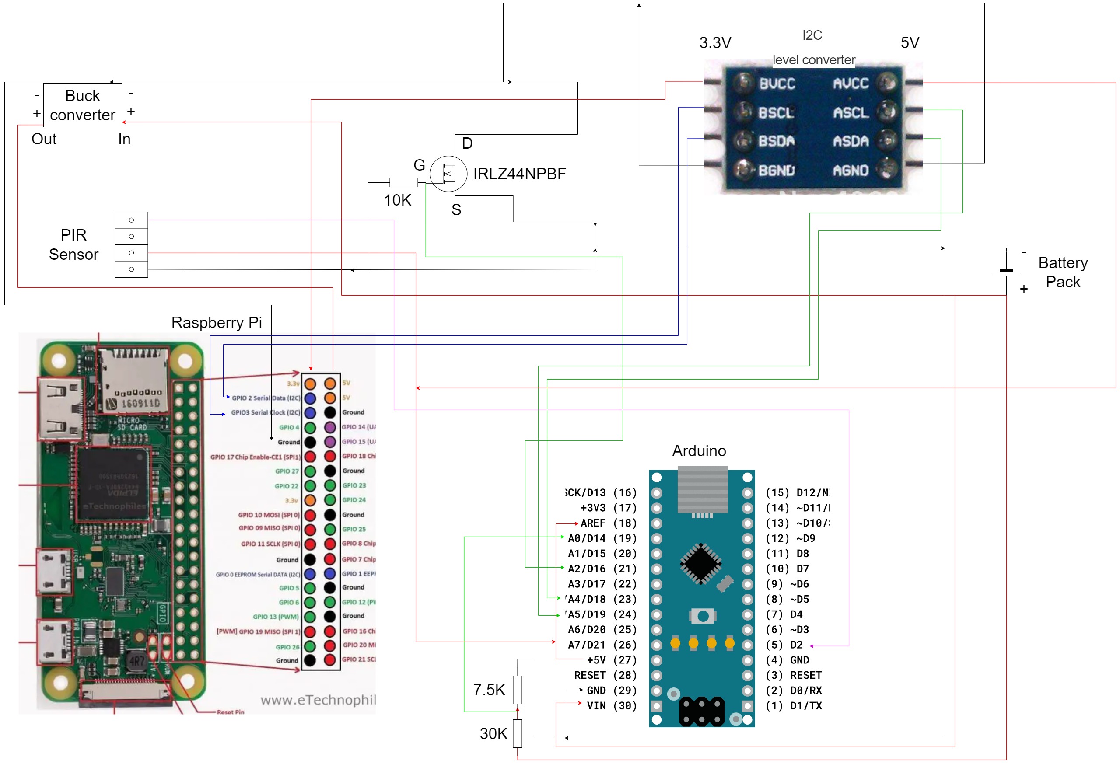
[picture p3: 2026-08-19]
hardware/pcb/trap-main/v3-docs/i2c-Pogo-diagram-V2.jpg

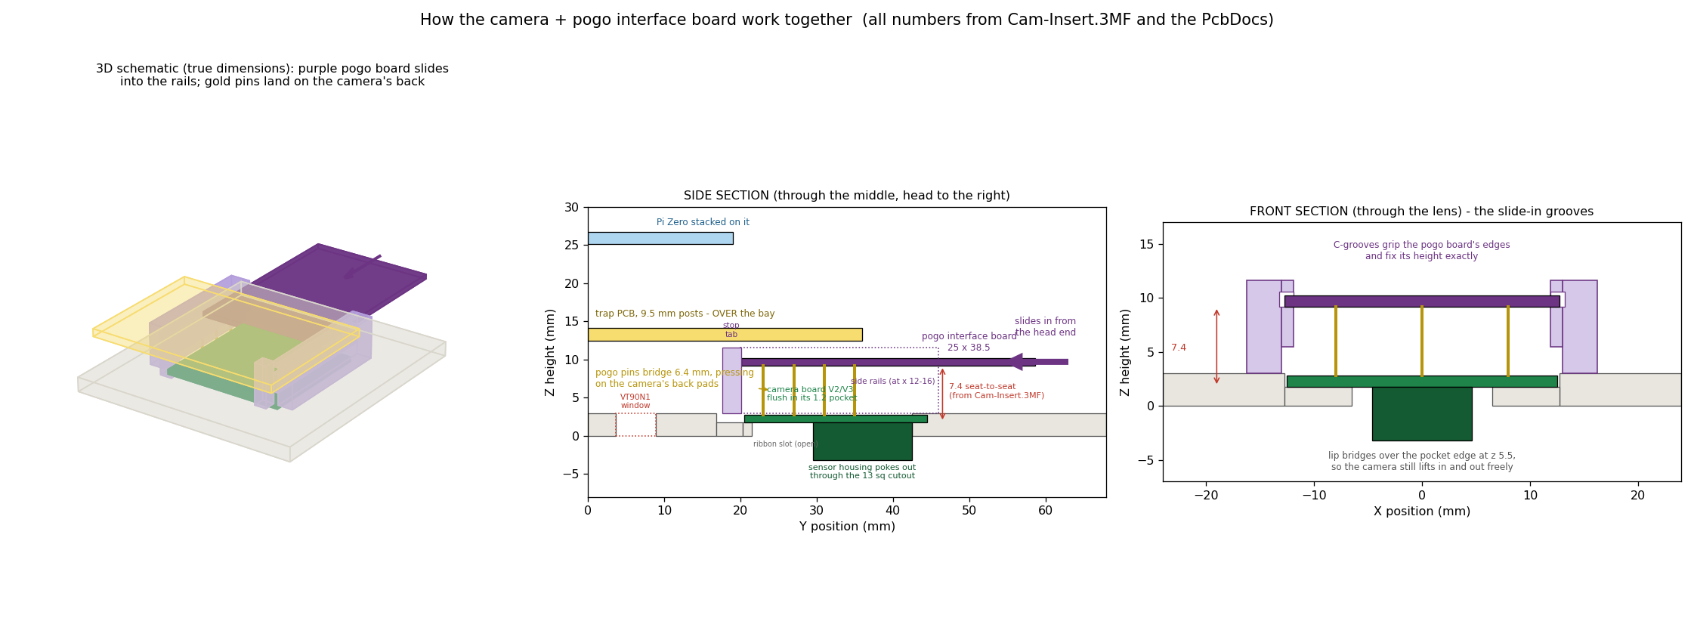
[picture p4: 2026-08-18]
enclosure/pogo_concept.png

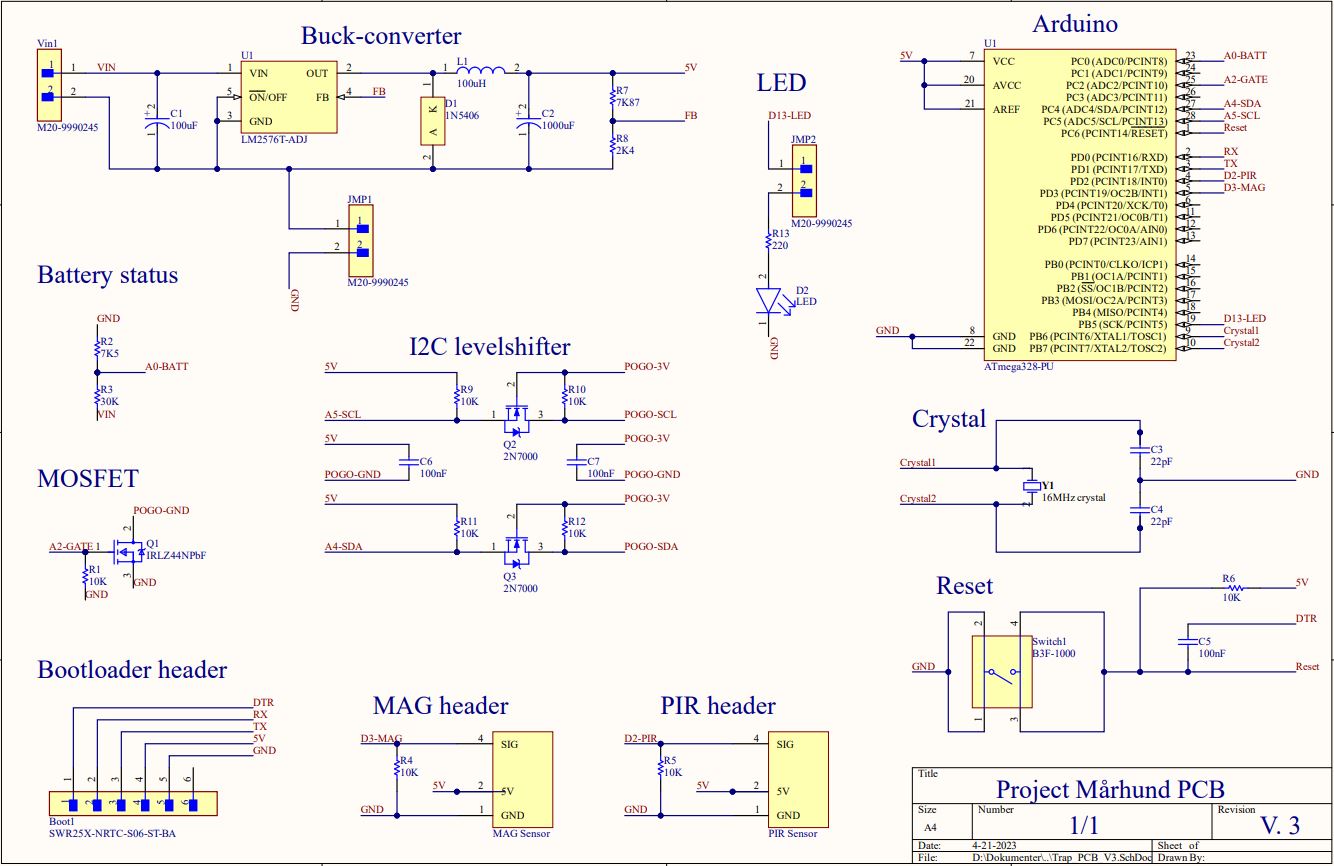
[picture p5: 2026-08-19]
hardware/pcb/trap-main/v3-docs/Schematic_V3.jpg

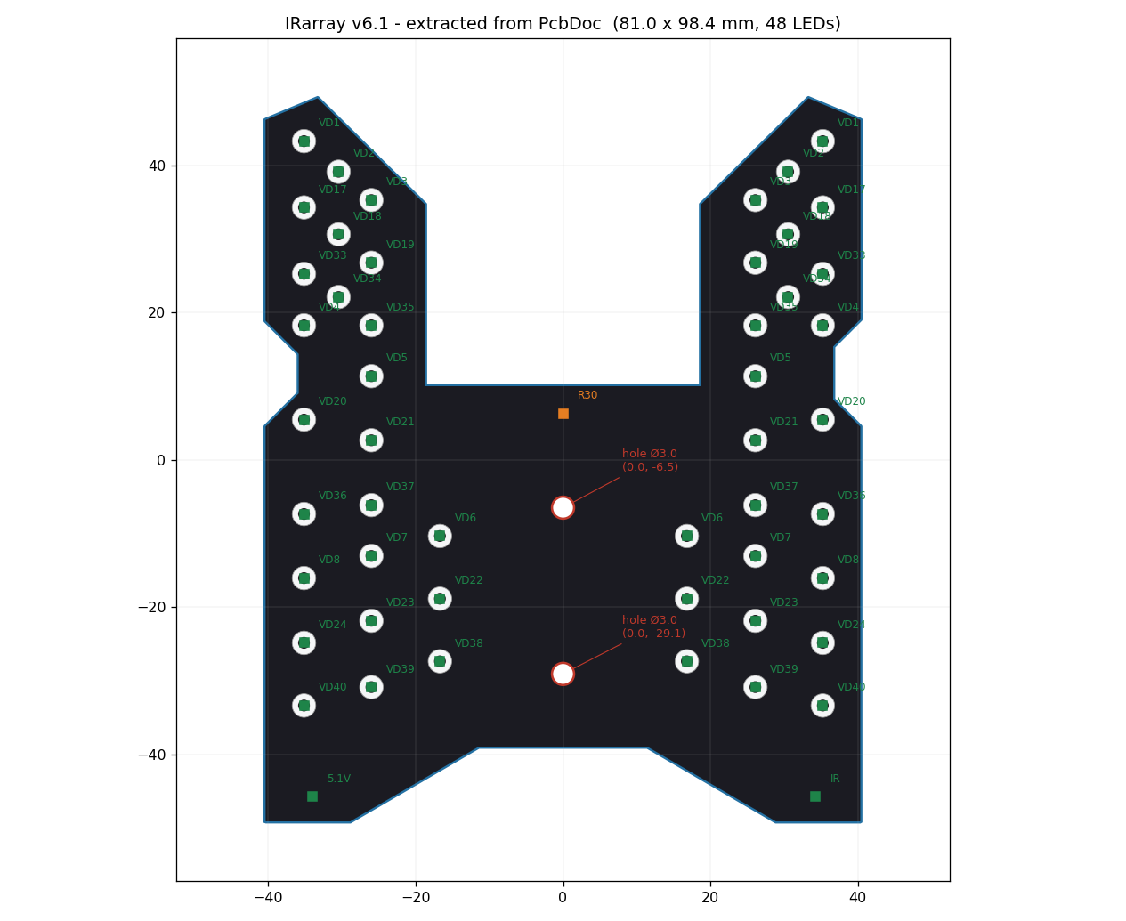
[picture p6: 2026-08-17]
enclosure/irboard_extracted.png

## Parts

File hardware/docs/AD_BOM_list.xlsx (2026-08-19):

Animal Detect BOM List
Item | Number | Price (excl VAT) | Possible decrease | New price (excl VAT) | Website | Price (excl VAT) | New price (excl VAT)
PIR sensor - Grove - Seeed Studio | 1 | 58.70 kr. | 0.4 | 23.48 kr. | Elfadistrelec (https://www.elfadistrelec.dk/da/grove-indstillelig-pir-bevaegelsessensor-seeed-studio-101020617/p/30135125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) | 2.53% | 1.71% | 1.48
REED sensor - Grove - Seeed Studio | 1 | 22.40 kr. | 0.4 | 8.96 kr. | RS (https://dk.rs-online.com/web/p/sensor-udvikling/1793718?matchtype=&gclsrc=aw.ds) | 0.97% | 0.65% | 1.48
Waveshare 4G Rpi hat | 1 | 535.20 kr. | 0.7 | 374.64 kr. | Raspberrypi.dk (https://raspberrypi.dk/produkt/sim7600g-h-4g-hat-b-til-raspberry-pi/) | 23.08% | 27.36% | 0.84
Raspberry Pi Zero 2 W | 1 | 119.20 kr. | 1 | 119.20 kr. | Raspberrypi.dk (https://raspberrypi.dk/produkt/sim7600g-h-4g-hat-b-til-raspberry-pi/) | 5.14% | 8.70% | 0.59
IR Camera with asscesories | 1 | 134.10 kr. | 0.5 | 67.05 kr. | Amazon.de (https://www.amazon.de/-/en/Compatible-Raspberry-Camera-Vision-Adjustable/dp/B08ZY7V5XW) | 5.78% | 4.90% | 1.18
SD card | 1 | 42.18 kr. | 0.5 | 21.09 kr. | Farnell (https://dk.farnell.com/en-DK/integral/inmsdh32g-100v10/32gb-microsdhc-v10-uhs-i-u1/dp/3498609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) | 1.82% | 1.54% | 1.18
Fillament | 1 | 156.00 kr. | 1 | 156.00 kr. | 3DEKSPERTEN (https://3deksperten.dk/products/spectrum-premium-pet-g-olive-green-1-75mm-1kg) | 6.73% | 11.39% | 0.59
Magnet | 1 | 36.00 kr. | 0.4 | 1.54 kr. | Magnetz | 1.55% | 0.11% | 13.81
SIM CARD | 6 | 192.00 kr. | 0.8 | 153.60 kr. | nemsim | 8.28% | 11.22% | 0.74
Scrws etc | 1 | 160.00 kr. | 0.5 | 80.00 kr. | All over the place | 6.90% | 5.84% | 1.18
Chargerboard | 1 | 120.00 kr. | 0.5 | 60.00 kr. | Let elektonik | 5.18% | 4.38% | 1.18
Chargerboard PCB | 1 | 30.00 kr. | 1 | 30.00 kr. | PCB Way | 1.29% | 2.19% | 0.59
Arduino board | 1 | 200.00 kr. | 0.6 | 120.00 kr. | PCB Way | 8.63% | 8.76% | 0.98
Batteries | 3 | 513.00 kr. | 0.3 | 153.90 kr. | RS | 22.12% | 11.24% | 1.97
Total |  | 2318.78 kr. | 92751.20 kr. | 1369.46 kr. | 40.94049457%
Price: | 2995.00 kr. | current: |  | possible:
 | Profit: | 676.22 kr. |  | 1625.54 kr.
 | profit %: | 22.57829716% |  | 54.27512521%
 |  | 2898.48 kr. | Hugo roughly estimates these initial costs on communicating with China: | 20000.00 kr.

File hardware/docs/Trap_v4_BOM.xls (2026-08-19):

 |  |  | Trap_v4 PCB'S BOM (Sample Bill of Materials)
Item # | *Designator | *Qty | Manufacturer | *Mfg Part # | Description / Value | *Package/Footprint | Type | Your Instructions / Notes / Links
1 | C2 | 1 | Panasonic | EEEFC1A102AP | 1000μF Electrolytic Capacitor 10V dc | Radial Can | SMD | https://uk.rs-online.com/web/p/aluminium-capacitors/7085812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
2 | R1 | 1 | VISHAY | TS53YJ105MR10 | single turn; 1MΩ; 250mW; SMD; ±20%; linear | TS53YJ | SMD | https://www.tme.eu/en/details/ts53yj1m/single-turn-smd-trimmers/vishay/ts53yj105mr10/
3 | J4 | 1 | HARWIN | M20-8770242 | 2 Way, 1 Row, Straight Pin Header | M20 | SMD | https://uk.rs-online.com/web/p/pcb-headers/6812903P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
4 | SW1 | 1 | TE Connectivity | 2-1437565-7 | TACTILE PB SWITCH Keypad Sw | FSM2JSMA | SMD | https://www.distrelec.biz/en/fsm2jsma-smt-tactile-pb-switch-keypad-sw-te-connectivity-1437565/p/30354157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
5 | Y1 | 1 | Abracon | ABLS-16.000MHZ-B4-T | ABLS-16.000MHZ-B4-T | HC49/US | SMD | https://uk.rs-online.com/web/p/crystal-units/1710560P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
6 | J3 | 1 | Samtec | SSM-106-L-SV | SSM 2.54mm Pitch 6 Way 1 Row Socket | Straight | SMD | https://uk.rs-online.com/web/p/pcb-sockets/7655408P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
7 | J1,J2 | 2 | Seeed Studio | 114020164 | Grove Female Headers, 4-Pin, Pitch 2mm, Angled | 90 x 61 x 15 MM | SMD | https://www.distrelec.biz/en/grove-female-headers-pin-pitch-2mm-angled-pack-of-20-pieces-seeed-studio-114020164/p/30180652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
8 | U1 | 1 | Microchip Technology | ATMEGA328P-AU | VR AVR® ATmega Mikrocontrollere IC 8-bit 20MHz 32KB (16K x 16) FLASH 32-TQFP (7x7) | 32-TQFP | SMD | https://www.digikey.dk/da/products/detail/microchip-technology/ATMEGA328P-AU/1832260?productid=1832260&gad=1
9 | L1 | 1 | TDK Corporation | CLF12577NIT-101M-D | 100 µH Shielded Drum Core, Wirewound Inductor 2.1 A 132mOhm Max Nonstandard | Nonstandard | SMD | https://www.digikey.dk/en/products/detail/tdk-corporation/CLF12577NIT-101M-D/6236928
10 | C1 | 1 | Panasonic | EEEHA1A101WP | 100μF Electrolytic Capacitor 10V dc | Radial Can | SMD | https://uk.rs-online.com/web/p/aluminium-capacitors/7472770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
11 | CR1 | 1 | Infineon | BAT60AE6327HTSA1 | 10V 3A, Schottky Diode, 2-Pin | SOD-323 | SMD | https://uk.rs-online.com/web/p/schottky-diodes-rectifiers/7527855P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
12 | D1 | 1 | Lite-On | LTST-C190GKT | 2.6 V Green LED | 1608 (0603) | SMD | https://uk.rs-online.com/web/p/leds/1689733?gb=s
13 | R11 | 1 | TE Connectivity | CRG0603F1M0 | 1MΩ Thick Film SMD Resistor ±1% 0.1W | 0603 (1608M) | SMD | https://uk.rs-online.com/web/p/surface-mount-resistors/1616303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
14 | R2 | 1 | Vishay | CRCW0805220RFKEAHP | Resistor 220 Ohm ±1% | 8050 | SMD | https://www.distrelec.biz/en/pulse-proof-high-power-thick-film-resistor-220ohm-0805-vishay-crcw0805220rfkeahp/p/30168019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
15 | R3,R4,R5,R6,R7,R8 | 6 | TE Connectivity | CRG1206F10K | 10kΩ Thick Film SMD Resistor ±1% 0.25W1206 (3216M) | 1206 (3216M) | SMD | https://uk.rs-online.com/web/p/surface-mount-resistors/1345524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
16 | R9 | 1 | Vishay | CRCW040230K0FKED | 30kΩ Thick Film SMD Resistor ±1% 0.063W | 0402 (1005M) | SMD | https://uk.rs-online.com/web/p/surface-mount-resistors/6789140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
17 | R10 | 1 | Vishay | CRCW04027K50FKED | 7.5kΩ Thick Film SMD Resistor ±1% 0.063W | 0402 (1005M) | SMD | https://uk.rs-online.com/web/p/surface-mount-resistors/6789576P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
18 | Q1 | 1 | Infineon | IRLZ44NSTRLPBF | Single - N-Channel, 55V, 47A | D2PAK | SMD | https://www.distrelec.biz/en/mosfet-single-channel-55v-47a-d2pak-infineon-irlz44nstrlpbf/p/30341413
19 | C5, C6 | 2 | Murata | GRM0335C1H220JA01D | 22pF Multilayer Ceramic Capacitor MLCC 50V dc ±5% | 0201 (0603M) | SMD | https://uk.rs-online.com/web/p/mlccs-multilayer-ceramic-capacitors/8202728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
20 | C7,C8,C9,C10,C11,C12 | 6 | KEMET | C0805X106M8RACTU | 10μF Multilayer Ceramic Capacitor MLCC 10V dc ±20% | 0805 (2012M) | SMD | https://uk.rs-online.com/web/p/mlccs-multilayer-ceramic-capacitors/1526063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
21 | C13,C14,C15,C16,C17,C18,C19 | 7 | KEMET | C0402C104K8PAC7867 | 100nF Ceramic Capacitor Multilayer Ceramic 10V 10% +Tol 10% -Tol X5R 15% TC 100nF | SMD 0402 | SMD | https://www.distrelec.biz/en/ceramic-capacitor-multilayer-ceramic-10v-10-tol-10-tol-x5r-15-tc-100nf-smd-0402-kemet-c0402c104k8pac7867/p/30312651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
22 | SR1 | 1 | Texas Instruments | LM2576HVS-ADJ/NOPB | Step-Down Switching Regulator, 1-Channel 3A Adjustable 5-Pin | D2PAK | SMD | https://uk.rs-online.com/web/p/buck-converters/0460487P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
23 | Q2,Q3 | 2 | DiodesZetex | BS170FTA | N-Channel MOSFET, 150 mA, 60 V, 3-Pin | SOT-23 | SMD | https://uk.rs-online.com/web/p/mosfets/2156587P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
24 | J5 | 1 | JST | 800943 | XH through hole connector 2 poles 3A | XHP2 | Through Hole | https://www.conradelektronik.dk/da/p/jst-stiftliste-standard-xh-samlet-antal-poler-2-rastermaal-2-50-mm-800943-1-stk-740155.html
 | Total components: | 43

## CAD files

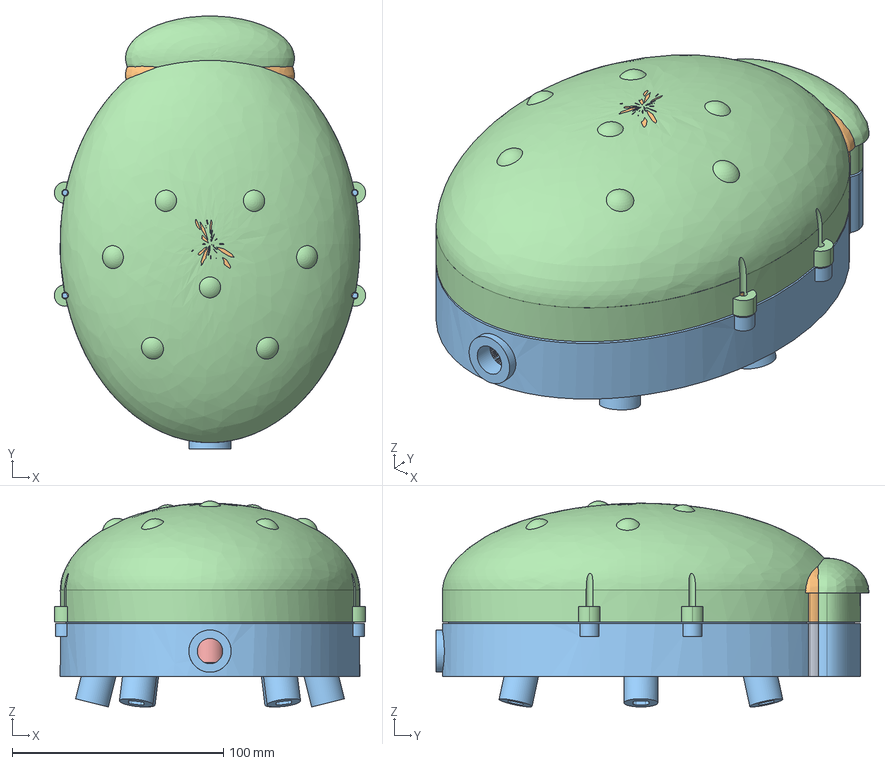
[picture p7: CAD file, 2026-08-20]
enclosure/ladybug.FCStd
147.4 x 205.0 x 97.5 mm
v1_1_belly
v1_1_shell
v1_2_belly
v1_2_shell
legs_leg_segment
legs_leg_segment_half
legs_foot

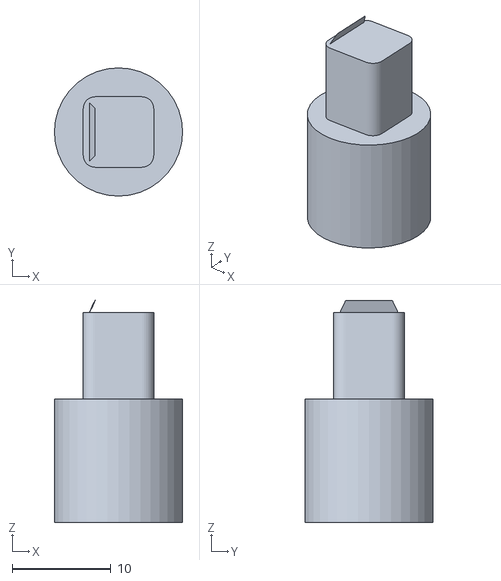
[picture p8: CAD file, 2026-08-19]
enclosure/stl/leg_segment_half.stl
13.0 x 13.0 x 22.5

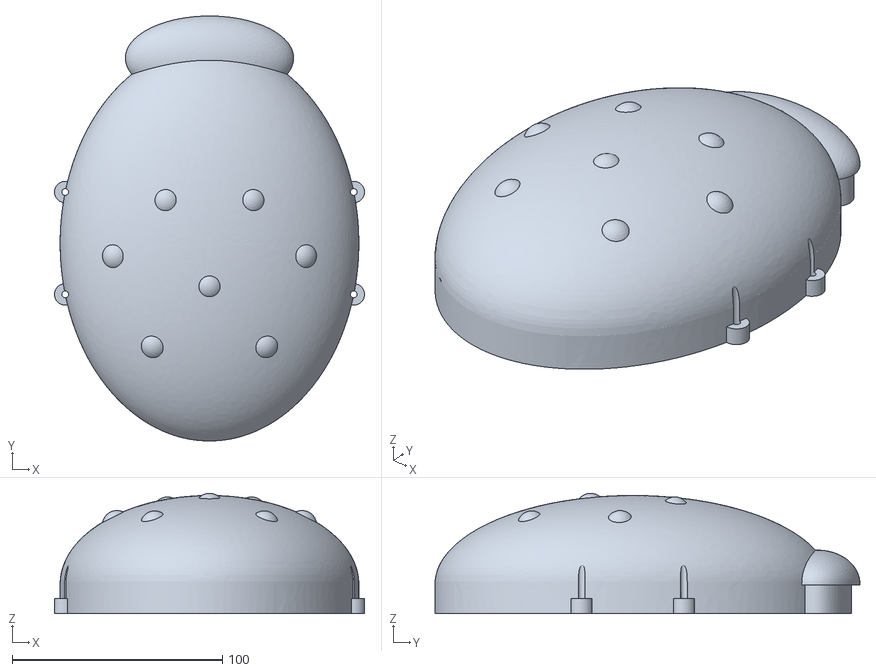
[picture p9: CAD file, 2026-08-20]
enclosure/stl/v1.2/shell.stl
147.4 x 202.0 x 57.2

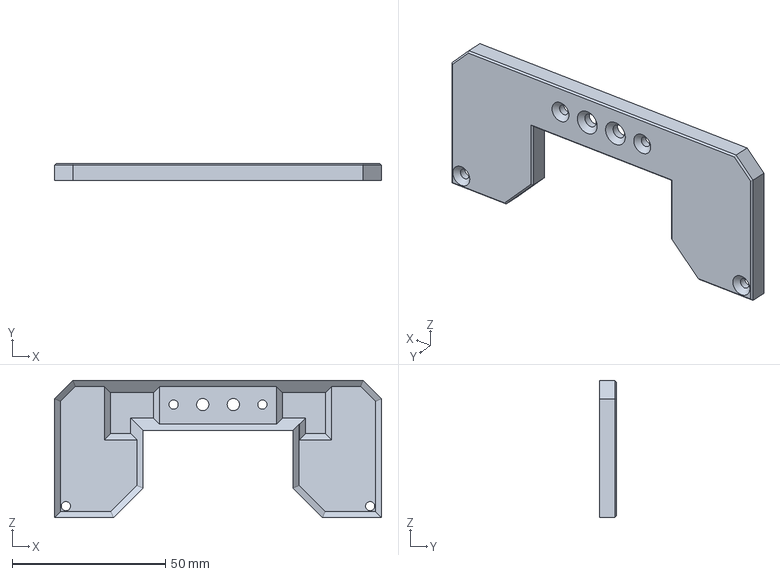
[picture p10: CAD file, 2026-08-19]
hardware/cad/Battery_Top.3MF
106.8 x 5.50 x 44.8 mm

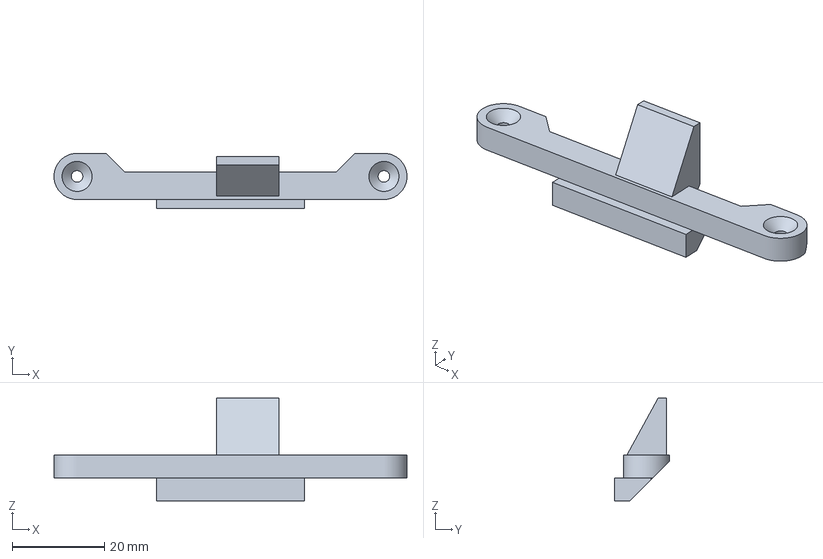
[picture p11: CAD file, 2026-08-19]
hardware/cad/TEST/BattPCB-Bracket.3MF
76.5 x 12.0 x 22.3 mm

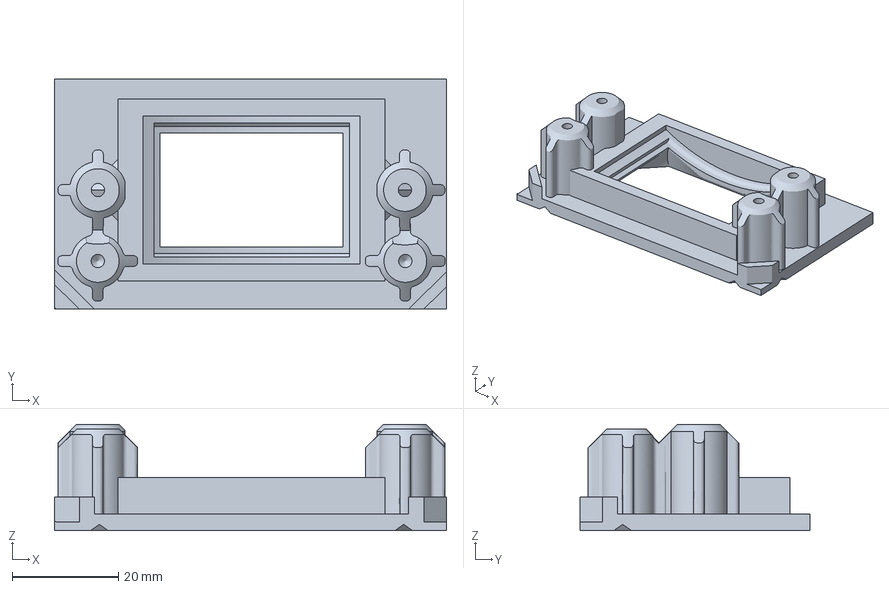
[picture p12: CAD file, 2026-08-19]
hardware/cad/TEST/New-PIR/Front-shell.3MF
73.6 x 43.3 x 20.0 mm

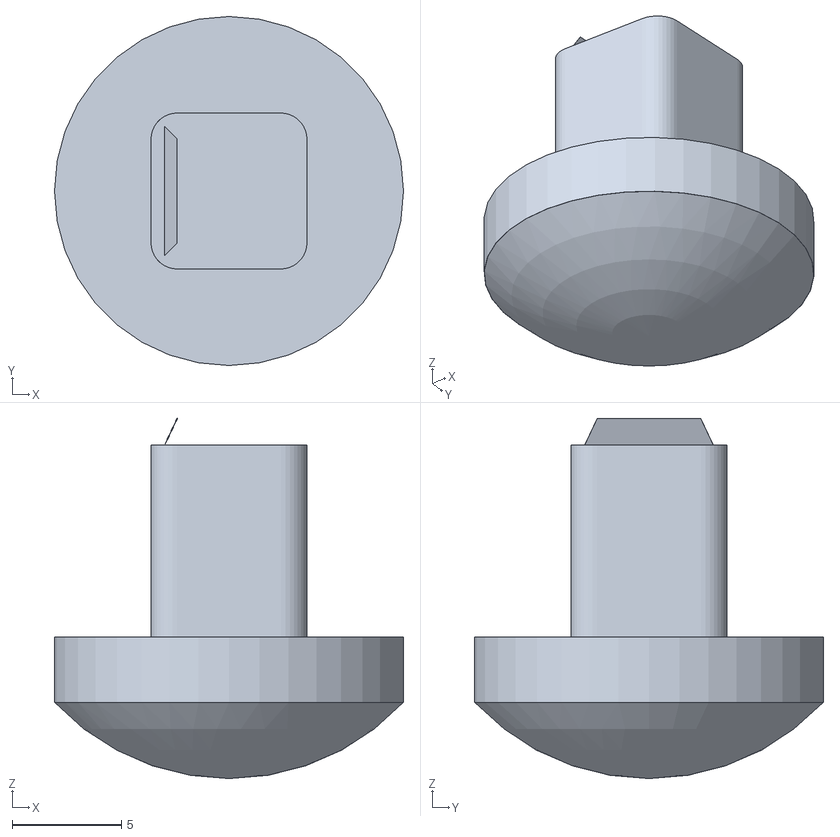
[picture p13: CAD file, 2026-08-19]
enclosure/stl/foot.stl
16.0 x 16.0 x 16.5

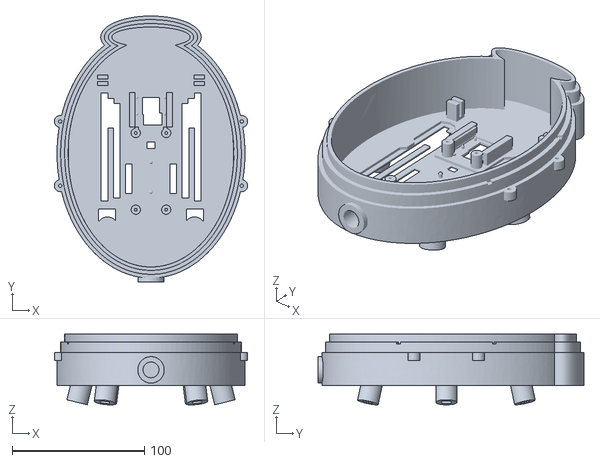
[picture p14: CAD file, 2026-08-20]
enclosure/stl/v1.2/belly.stl
146.2 x 201.0 x 53.5

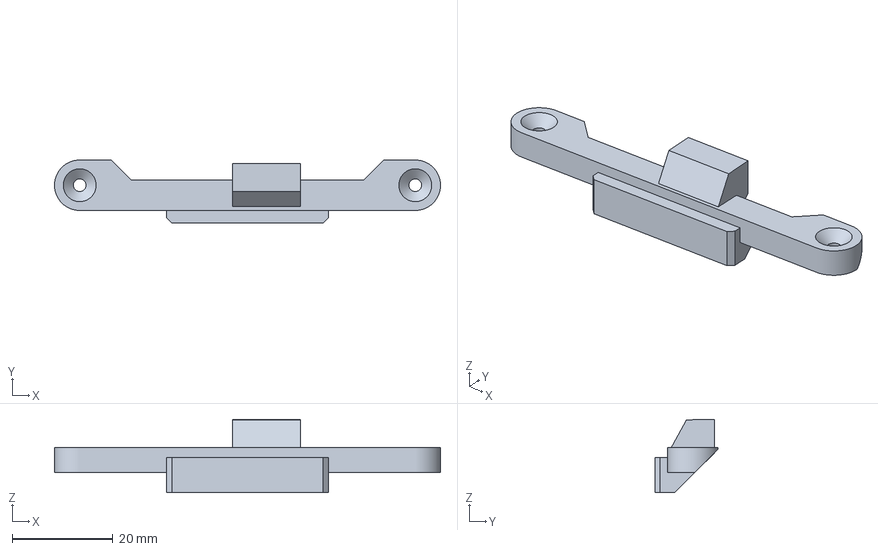
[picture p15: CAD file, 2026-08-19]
hardware/cad/BattPCB-Bracket.3MF
76.5 x 12.5 x 14.6 mm

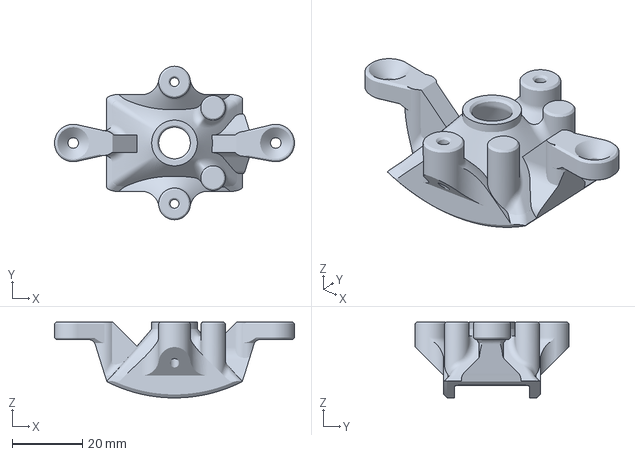
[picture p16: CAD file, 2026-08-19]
hardware/cad/TEST/New-PIR/PIR-Funnel.3MF
68.3 x 43.7 x 21.6 mm

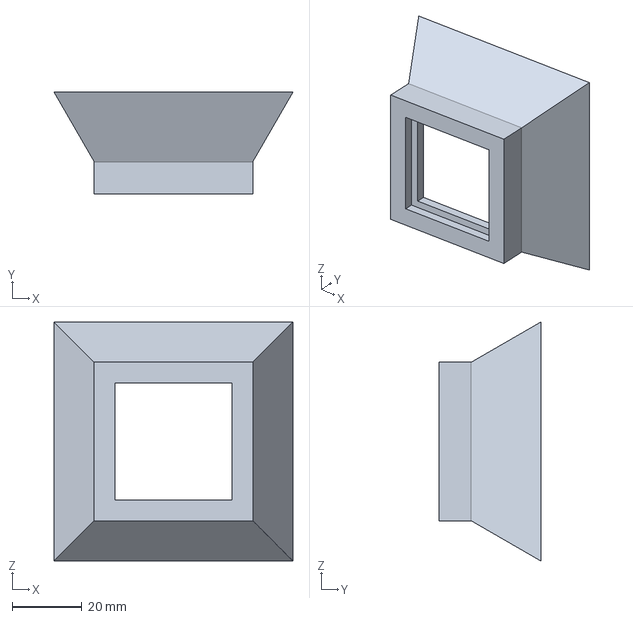
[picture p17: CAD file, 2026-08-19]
hardware/cad/TEST/PET-G_Test.3MF
68.6 x 29.2 x 68.6 mm

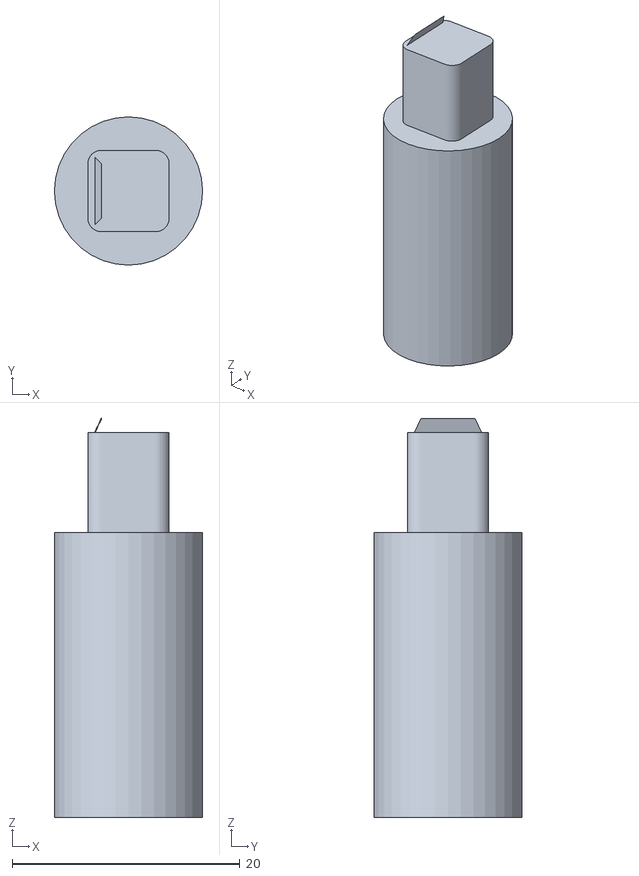
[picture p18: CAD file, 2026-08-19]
enclosure/stl/leg_segment.stl
13.0 x 13.0 x 35.0

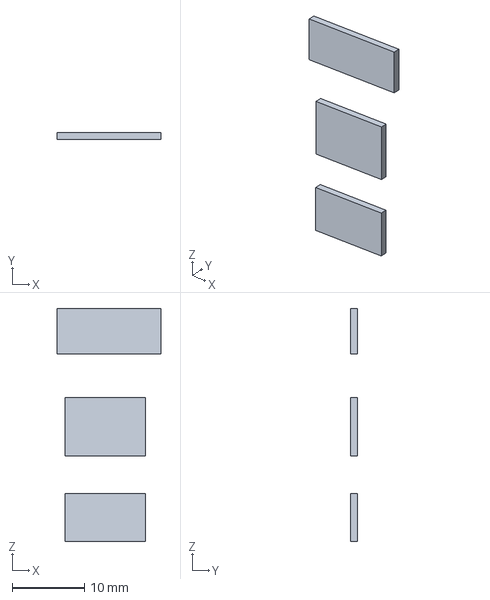
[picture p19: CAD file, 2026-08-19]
hardware/cad/Charger-IconInlay.3MF
14.4 x 1.00 x 32.3 mm

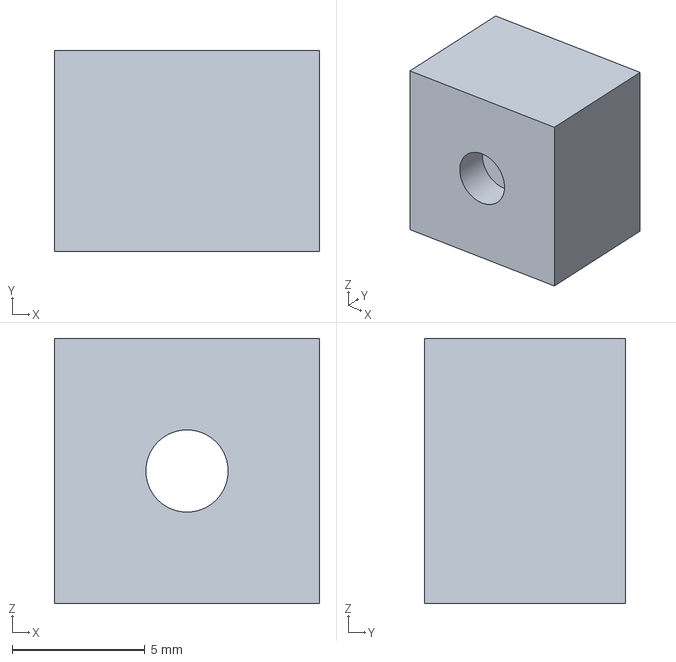
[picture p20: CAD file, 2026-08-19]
hardware/cad/TEST/M3-test.3MF
10.0 x 7.60 x 10.0 mm

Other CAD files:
hardware/cad/TEST/New-PIR/PIRbracket.3MF
hardware/cad/Shade.3MF
hardware/cad/TEST/Back-shell.3MF
hardware/cad/AntennaSafeInsert.3MF
enclosure/stl/v1.1/belly.stl
enclosure/stl/v1.1/shell.stl
hardware/cad/AntennaSafe.3MF
hardware/cad/AntennaSafeTip.3MF
hardware/cad/Back-shell.3MF
hardware/cad/Battery-Knob.3MF
hardware/cad/Battery_Buttom.3MF
hardware/cad/Bracket.3MF
hardware/cad/Cam-Insert.3MF
hardware/cad/Charger-Top.3MF
hardware/cad/Charger-buttom.3MF
hardware/cad/Front-shell.3MF
hardware/cad/IR-Insert-Folding.3MF
hardware/cad/PIR-Funnel.3MF
hardware/cad/PIRbracket.3MF
hardware/cad/Shade - Big.3MF
hardware/cad/TEST/Front-shell.3MF
hardware/cad/TEST/PET-TEST.3MF
hardware/cad/Tree-Knob.3MF
hardware/cad/TreeBracket.3MF

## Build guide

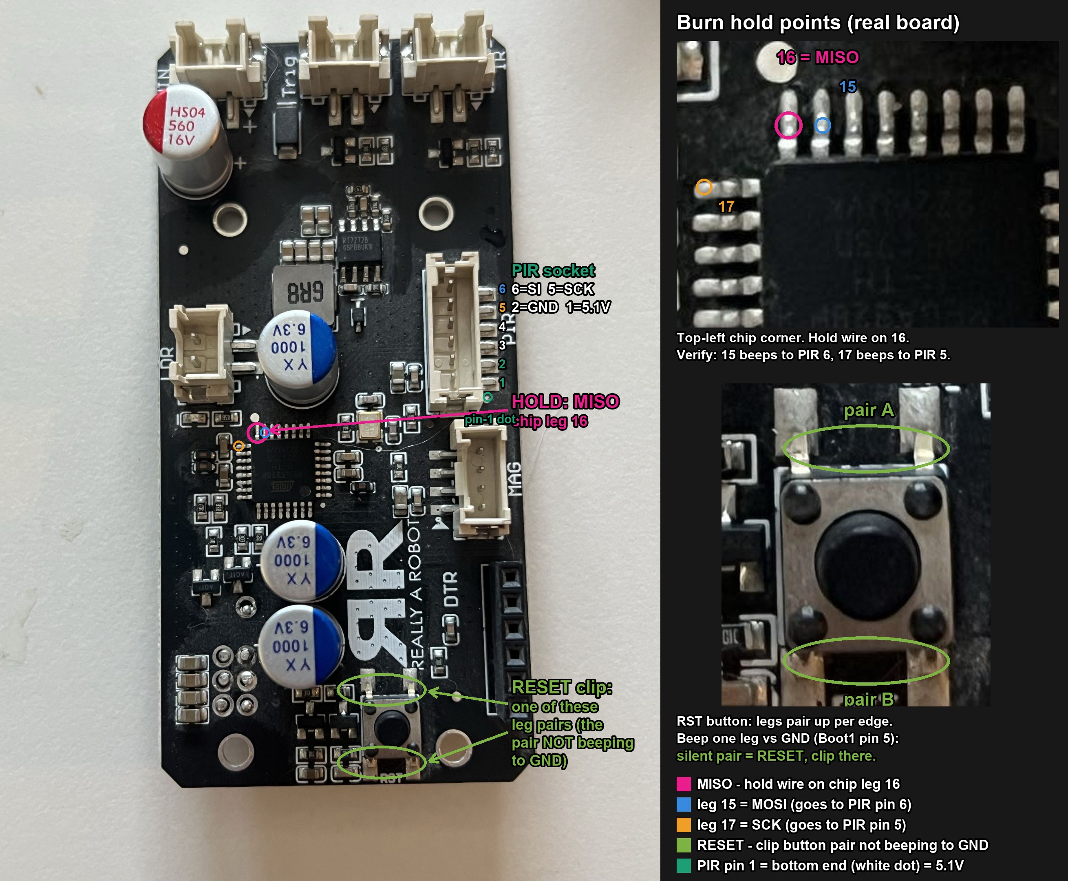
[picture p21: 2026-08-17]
docs/burn_wiring_photo.jpg

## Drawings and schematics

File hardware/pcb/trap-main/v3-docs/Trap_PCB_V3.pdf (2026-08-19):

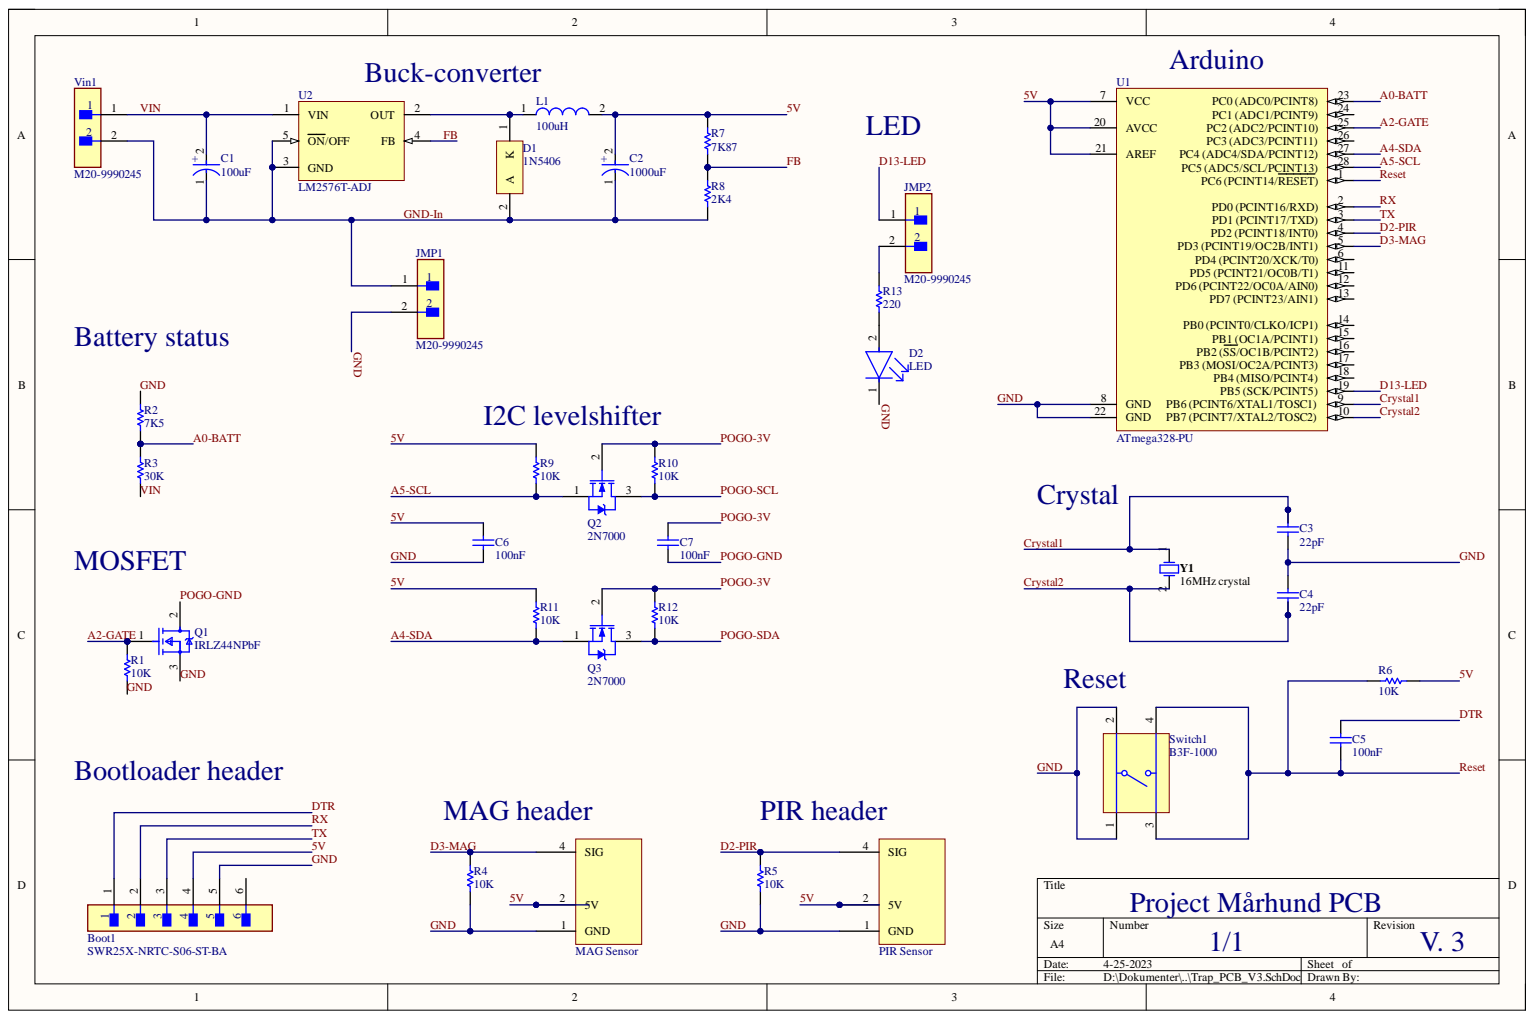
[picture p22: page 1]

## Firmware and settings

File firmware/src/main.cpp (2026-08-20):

// Project Mariehoene — timelapse firmware for the AD Trap PCB V3.3 (ATmega328P @ 16 MHz).
// Derived from the Animal Detect arduino-controller (2024-04-22 snapshot); keeps the
// same I2C slave protocol so the existing RPi stack keeps working unmodified.
//
// Instead of PIR-triggered captures, the RPi is power-cycled on a fixed interval
// (default every DEFAULT_INTERVAL_SECONDS), with an optional daily quiet window
// during which nothing is captured. PIR/reed triggers can be re-enabled below.

#include <Arduino.h>
#include <Wire.h>
#include <LowPower.h>
#include <avr/sleep.h>
#include <avr/wdt.h>
#include <SPI.h>

// ------------------------------------------------------------------ build config
#define ENABLE_PIR_TRIGGER 0            // 1 = also capture on PIR motion
#define ENABLE_REED_TRIGGER 0           // 1 = also capture on reed/magnet
#define ENABLE_BATTERY_GUARD 0          // bench-safe default; set 1 for FIELD builds
                                        // (needs a real battery on A0 - a floating
                                        //  pin reads garbage and would sleep the MCU)
#define DEFAULT_INTERVAL_SECONDS 60UL   // timelapse cadence (min 15 recommended)

// ------------------------------------------------------------------ pins (board-fixed)
#define I2C_ADDRESS 0x08
#define BAUDRATE 9600
#define PIR_PIN 2
#define REED_PIN 3
#define TRIGGER_PIN 4
#define FLASH_PIN 5
#define CHIP_SELECT 10                  // digipot on the PIR sensor board
#define RELAY_PIN 16                    // A2-GATE: high-side switch for RPi power
#define LED_PIN 13                      // shares the SCK net
#define PHOTORESISTOR_PIN A1
#define BATTERY_CAPACITY_PIN A0

// ------------------------------------------------------------------ I2C commands
#define CMD_TIME 0x00                   // w: s,m,h
#define CMD_SETUP_STATUS 0x01           // r
#define CMD_BATTERY_LEVEL 0x02          // r
#define CMD_ACTIVATION_TYPE 0x03        // r: 1 PIR, 2 ping, 3 reed, 4 timelapse
#define CMD_SET_PING_INTERVAL 0x04      // w: hours
#define CMD_SET_PING_TIME 0x05          // w: h,m,s
#define CMD_SET_IGNORE_TIME 0x06        // w: from h,m,s + to h,m,s (quiet window)
#define CMD_TURN_OFF_RPI_INTEGER 0x07   // r: RPi asks us to cut its power
#define CMD_FLASH_ON 0x08               // w: duration s
#define CMD_SET_DUSK_VALUE 0x09         // w: value/4
#define CMD_IMAGE_TYPE 0x0A             // r
#define CMD_SET_PIR_VALUE 0x0B          // w: digipot 1..254
#define CMD_SET_TIME_INTERVAL 0x0C      // w: minutes (254 = 0) — legacy
#define CMD_SET_TIMELAPSE_SECONDS 0x0D  // w: 2 bytes, seconds = hi<<8 | lo — new
#define CMD_SET_ALWAYS_ON 0x0E          // w: 1 byte 0/1 — 1 = never cut RPi power on timeout
#define CMD_SET_OUTPUT 0x0F             // w: 2 bytes: pin (0=IR, 1=Trig, 2=RPi gate), state 0/1
#define CMD_READ_PIR 0x10               // r: PIR input level
#define CMD_READ_MAG 0x11               // r: reed/MAG input level
#define CMD_READ_LDR 0x12               // r: photoresistor, analog/4 (0-255)
#define CMD_READ_BATT_DV 0x13           // r: battery voltage in decivolts (74 = 7.4 V)
#define CMD_READ_VERSION 0x14           // r: firmware version
#define CMD_SET_MAX_ON_TIME 0x15        // w: 1 byte seconds (10-255) — RPi on-time budget

#define FW_VERSION 2

// trigger reasons reported to the RPi
#define TRIGGER_PIR 1
#define TRIGGER_PING 2
#define TRIGGER_REED 3
#define TRIGGER_TIMELAPSE 4

// ------------------------------------------------------------------ time keeping
// Timer2 free-runs with /1024 prescaler; at 16 MHz that is 61.04 overflows per
// second, and it keeps running in SLEEP_MODE_PWR_SAVE thanks to the AS2 trick
// inherited from the original firmware (the 16 MHz crystal stays active).
// NOTE: the WiFi timelapse (timelapse.py) never sends CMD_TIME, so this wall
// clock free-runs from 00:00 and drifts (~0.06%/day from the 61-vs-61.04
// rounding). It is ONLY used by the ping / quiet-window paths — if you enable
// those, have the RPi send 0x00 periodically to keep it accurate.
struct Time {
    int hours, minutes, seconds;
    void tick() {
        if (++seconds >= 60) { seconds = 0;
            if (++minutes >= 60) { minutes = 0;
                if (++hours >= 24) hours = 0; } }
    }
};

volatile unsigned long overflowCounter = 0;
volatile unsigned long sleepPeriods = 0;         // seconds since boot (monotonic)
volatile unsigned long totalMilliseconds = 0;
Time updateTimeStruct;                           // wall clock, synced by the RPi

ISR(TIMER2_OVF_vect) {
    if (++overflowCounter >= 61) {               // 61 overflows ~= 1 second
        overflowCounter = 0;
        sleepPeriods++;
        totalMilliseconds += 1000;
        updateTimeStruct.tick();
    }
}

unsigned long getElapsedTime() {
    uint8_t sreg = SREG; cli();                  // save + restore interrupt state
    unsigned long elapsed = totalMilliseconds;   // (never force sei() blindly)
    SREG = sreg;
    return elapsed;
}

unsigned long nowSeconds() {
    uint8_t sreg = SREG; cli();
    unsigned long s = sleepPeriods;
    SREG = sreg;
    return s;
}

// ------------------------------------------------------------------ state
volatile unsigned long intervalSeconds = DEFAULT_INTERVAL_SECONDS;
unsigned long nextShotAt = 0;                    // in sleepPeriods seconds

Time pingTime = {8, 0, 0};
Time ignoreTimeFrom = {0, 0, 0};                 // from==to means "no quiet window"
Time ignoreTimeTo = {0, 0, 0};
volatile int pingInterval = 12;                  // hours
int lastDisplayedMinute = -1;
bool sendPing = false;

// Pre-always-on on-time budget. Raised from 80 s so a slow first boot (SD
// expansion, service start) can't cut power before timelapse.py sends 0x0E.
volatile long maxRaspberryPiOnTime = 150000;     // ms the RPi may stay up per cycle
volatile int requestNumber = 0;                  // 3 = RPi requested shutdown
volatile int triggerReason = TRIGGER_PING;
bool initializationComplete = false;
volatile bool alwaysOn = false;                  // never cut RPi power on timeout (cmd 0x0E)
volatile bool powerCutRequested = false;         // explicit gate-off via 0x0F pin 2 state 0

// IR flash (touched by the I2C ISR + main loop -> volatile)
volatile bool flashOn = false;
volatile unsigned long flashDuration = 2;        // seconds
volatile int duskValue = 600;
volatile int imageType = 0;                      // 0 RGB, 1 IR

// digipot (PIR sensitivity — kept for protocol compatibility)
byte digiPotAddress = 0x11;
volatile int digiPotValue = 254;
volatile bool digipotChangeStatus = false;

// Sensor values sampled in the main loop and returned by the I2C ISR. Never
// sample in the ISR: analogRead (~112 us) / digitalRead there stalls the bus.
volatile int cachedPir = 0, cachedMag = 0, cachedLdr = 0, cachedBattDv = 0;

// battery
const float R1 = 30000.0, R2 = 7500.0;
const float refVoltage = 5.0;
const float voltageOffset = 0.15;
const float minVoltage = 6.0, maxVoltage = 8.0;
const float minVoltageOffset = 0.6;
const float maxBatteryVoltage = 8.8;
float inVoltage = 0.0;
float prevBatteryLevel = 0, prevBatteryPercent = -1;
volatile unsigned int procentVolt = 0;

#if ENABLE_PIR_TRIGGER
volatile byte pirState = LOW, prevPirState = HIGH;
#endif
#if ENABLE_REED_TRIGGER
volatile byte reedState = LOW, prevReedState = LOW;
int reedStabilityCounter = 0, reedHighCounter = 0;
const int consecutiveReedValue = 5;
bool reedConfirmedLow = false;
#endif

// ------------------------------------------------------------------ helpers
void digitalPotWrite(int value) {
    digitalWrite(CHIP_SELECT, LOW);
    SPI.transfer(digiPotAddress);
    SPI.transfer(value);
    digitalWrite(CHIP_SELECT, HIGH);
}

void applyPendingDigipot() {
    if (!digipotChangeStatus) return;
    for (int i = 0; i < 3; i++) {
        digitalPotWrite(digiPotValue);
        delay(500);
    }
    digipotChangeStatus = false;
    Serial.print(F("Digipot set to "));
    Serial.println(digiPotValue);
}

unsigned int batteryCapacity() {
    float adcVoltage = 0;
    for (int i = 0; i < 100; i++)
        adcVoltage += ((analogRead(BATTERY_CAPACITY_PIN) * refVoltage) / 102400.0);
    inVoltage = adcVoltage / (R2 / (R1 + R2)) + voltageOffset;
    cachedBattDv = constrain((int)(inVoltage * 10.0 + 0.5), 0, 255);  // for I2C 0x13
    if (inVoltage > maxVoltage) procentVolt = 100;
    else if (inVoltage <= minVoltage) procentVolt = 1;
    else procentVolt = max(1U, (unsigned int)((100 * (inVoltage - minVoltage)) / (maxVoltage - minVoltage)));
    // suppress small upward jitter
    if (procentVolt > prevBatteryLevel && procentVolt <= prevBatteryLevel + 2)
        procentVolt = prevBatteryLevel;
    else
        prevBatteryLevel = procentVolt;
    Serial.print(F("Battery: "));
    Serial.print(inVoltage, 2);
    Serial.print(F(" V, "));
    Serial.print(procentVolt);
    Serial.println(F(" %"));
    return procentVolt;
}

void checkBatteryStatus() {
#if ENABLE_BATTERY_GUARD
    unsigned int current = batteryCapacity();
    bool outOfRange = inVoltage < minVoltage - minVoltageOffset || inVoltage > maxBatteryVoltage;
    if (outOfRange) {
        // Always confirm with a second reading - one transient/floating sample
        // must never latch a permanent shutdown.
        Serial.println(F("Battery out of range - re-measuring in 10 s"));
        delay(10000);
        current = batteryCapacity();
        if (inVoltage < minVoltage - minVoltageOffset || inVoltage > maxBatteryVoltage) {
            Serial.println(F("Battery out of range (confirmed) - shutting down"));
            digitalWrite(RELAY_PIN, LOW);
            LowPower.powerDown(SLEEP_FOREVER, ADC_OFF, BOD_OFF);
            return;
        }
    }
    prevBatteryPercent = current;
#else
    batteryCapacity();  // still measured/reported, never fatal
#endif
}

bool isTimeWithinRange(Time c, Time s, Time e) {
    if (s.hours == e.hours && s.minutes == e.minutes && s.seconds == e.seconds)
        return false;                            // window disabled
    long cur = c.hours * 3600L + c.minutes * 60L + c.seconds;
    long start = s.hours * 3600L + s.minutes * 60L + s.seconds;
    long end = e.hours * 3600L + e.minutes * 60L + e.seconds;
    if (start < end) return cur >= start && cur <= end;
    return cur >= start || cur <= end;           // window crosses midnight
}

bool isPingTime(Time c, Time p, int interval) {
    if (c.hours == p.hours && c.minutes == p.minutes) return true;
    int diff = (c.hours * 60 + c.minutes) - (p.hours * 60 + p.minutes);
    if (diff < 0) diff += 24 * 60;
    return interval > 0 && diff % (interval * 60) == 0;
}

void handleMinuteChange() {
    if (updateTimeStruct.minutes != lastDisplayedMinute) {
        lastDisplayedMinute = updateTimeStruct.minutes;
        if (isPingTime(updateTimeStruct, pingTime, pingInterval)) {
            sendPing = true;
            Serial.println(F("Ping time"));
        }
    }
}

void handleFlash() {
    static bool isFlashActive = false;
    static unsigned long flashStart = 0;
    if (flashOn && !isFlashActive) {
        int light = analogRead(PHOTORESISTOR_PIN);
        if (light < duskValue || duskValue == 1023) {
            digitalWrite(FLASH_PIN, HIGH);
            isFlashActive = true;
            flashStart = nowSeconds();
            imageType = 1;
            Serial.println(F("Flash on (IR)"));
        } else {
            flashOn = false;
            imageType = 0;
            Serial.println(F("Flash skipped - bright enough"));
        }
    } else if (isFlashActive && (nowSeconds() - flashStart >= flashDuration)) {
        digitalWrite(FLASH_PIN, LOW);
        isFlashActive = false;
        flashOn = false;
        Serial.println(F("Flash off"));
    }
}

// ------------------------------------------------------------------ I2C slave
// receiveEvent / requestEvent run in the TWI interrupt with interrupts OFF, so
// they must NOT do Serial I/O (busy-waits on a buffer drained by another ISR ->
// deadlock) or analogRead (~112 us bus stall). They only latch bytes into state
// and return values the main loop has cached. Any logging happens in loop().
void receiveEvent(int howMany) {
    if (howMany < 2) return;
    int command = Wire.read();
    switch (command) {
        case CMD_TIME:
            if (howMany == 4) {
                updateTimeStruct.seconds = Wire.read();
                updateTimeStruct.minutes = Wire.read();
                updateTimeStruct.hours = Wire.read();
            }
            break;
        case CMD_SET_PING_INTERVAL:
            if (howMany == 2) pingInterval = Wire.read();
            break;
        case CMD_SET_PING_TIME:
            if (howMany == 4) {
                pingTime.hours = Wire.read();
                pingTime.minutes = Wire.read();
                pingTime.seconds = Wire.read();
            }
            break;
        case CMD_SET_IGNORE_TIME:
            if (howMany == 7) {
                ignoreTimeFrom.hours = Wire.read();
                ignoreTimeFrom.minutes = Wire.read();
                ignoreTimeFrom.seconds = Wire.read();
                ignoreTimeTo.hours = Wire.read();
                ignoreTimeTo.minutes = Wire.read();
                ignoreTimeTo.seconds = Wire.read();
            }
            break;
        case CMD_FLASH_ON:
            if (howMany == 2) { flashOn = true; flashDuration = Wire.read(); }
            break;
        case CMD_SET_DUSK_VALUE:
            if (howMany == 2) {
                duskValue = Wire.read() * 4;
                if (duskValue > 1000) duskValue += 3;   // nudge onto the 1023 "always-flash" sentinel
            }
            break;
        case CMD_SET_PIR_VALUE:
            if (howMany == 2) {
                digiPotValue = max(1, min((int)Wire.read(), 254));
                digipotChangeStatus = true;
            }
            break;
        case CMD_SET_TIME_INTERVAL:                    // legacy: minutes
            if (howMany == 2) {
                int m = Wire.read();
                intervalSeconds = (m == 254) ? DEFAULT_INTERVAL_SECONDS : (unsigned long)m * 60UL;
                if (intervalSeconds == 0) intervalSeconds = DEFAULT_INTERVAL_SECONDS;
            }
            break;
        case CMD_SET_TIMELAPSE_SECONDS:                // new: seconds, 16-bit
            if (howMany == 3) {
                unsigned int hi = Wire.read(), lo = Wire.read();
                unsigned long s = ((unsigned long)hi << 8) | lo;
                if (s >= 15) intervalSeconds = s;      // below ~15 s the RPi can't finish a cycle
            }
            break;
        case CMD_SET_ALWAYS_ON:
            if (howMany == 2) alwaysOn = Wire.read() != 0;
            break;
        case CMD_SET_OUTPUT:
            if (howMany == 3) {
                int pinId = Wire.read();
                int state = Wire.read() ? HIGH : LOW;
                if (pinId == 2) {                      // RPi power gate
                    if (state == LOW) powerCutRequested = true;  // honored by the capture loop
                    else digitalWrite(RELAY_PIN, HIGH);
                } else if (pinId == 0) {
                    digitalWrite(FLASH_PIN, state);    // digitalWrite is ISR-safe (fast)
                } else if (pinId == 1) {
                    digitalWrite(TRIGGER_PIN, state);
                }
            }
            break;
        case CMD_SET_MAX_ON_TIME:
            if (howMany == 2) {
                int s = Wire.read();
                if (s >= 10) maxRaspberryPiOnTime = (long)s * 1000L;
            }
            break;
        default:
            break;
    }
}

void requestEvent() {
    int command = Wire.read();
    int requestedData = 0;
    switch (command) {
        case CMD_SETUP_STATUS:    requestedData = initializationComplete ? 1 : 0; break;
        case CMD_BATTERY_LEVEL:   requestedData = procentVolt; break;
        case CMD_ACTIVATION_TYPE: requestedData = triggerReason; break;
        case CMD_IMAGE_TYPE:      requestedData = imageType; break;
        case CMD_TURN_OFF_RPI_INTEGER: requestNumber = 3; break;
        case CMD_READ_PIR:        requestedData = cachedPir; break;
        case CMD_READ_MAG:        requestedData = cachedMag; break;
        case CMD_READ_LDR:        requestedData = cachedLdr; break;
        case CMD_READ_BATT_DV:    requestedData = cachedBattDv; break;
        case CMD_READ_VERSION:    requestedData = FW_VERSION; break;
        default:                  requestedData = -1; break;
    }
    Wire.write(requestedData);
}

// Sample sensors in the main loop so the I2C ISR can return cached values.
void sampleSensors() {
    cachedPir = digitalRead(PIR_PIN);
    cachedMag = digitalRead(REED_PIN);
    cachedLdr = analogRead(PHOTORESISTOR_PIN) >> 2;    // 0-255
}

// ------------------------------------------------------------------ capture cycle
// Powers the RPi, services the I2C handshake until it requests shutdown (or a
// timeout hits, 3 attempts), cuts power, then schedules the next slot.
void runCaptureCycle(int reason) {
    triggerReason = reason;
    unsigned long cycleStart = nowSeconds();
    requestNumber = 0;

    digitalWrite(LED_PIN, HIGH);                 // heartbeat blink (LED shares SCK)
    delay(30);
    digitalWrite(LED_PIN, LOW);

    checkBatteryStatus();
    Serial.print(F("Capture cycle, reason "));
    Serial.println(reason);

    TWCR = (1 << TWEN);                          // re-arm I2C after sleep
    Wire.begin(I2C_ADDRESS);

    int retry_count = 0;
    unsigned long timerStart = getElapsedTime();
    digitalWrite(RELAY_PIN, HIGH);               // RPi on

    // In always-on the timeout branch simply never fires, so this loops until the
    // RPi requests shutdown (0x07) or an explicit gate-off (0x0F pin 2 -> 0).
    while (retry_count < 3) {
        handleFlash();
        sampleSensors();
        long elapsed = (long)(getElapsedTime() - timerStart);
        if (digitalRead(RELAY_PIN) == LOW && !powerCutRequested) digitalWrite(RELAY_PIN, HIGH);

        if (requestNumber == 3 || powerCutRequested) {   // RPi done, or explicit gate-off
            requestNumber = 0;
            powerCutRequested = false;
            initializationComplete = true;
            digitalWrite(RELAY_PIN, LOW);
            Serial.println(F("RPi power cut"));
            delay(2000);                         // let rails drain / sensors settle
            applyPendingDigipot();
            break;
        }
        if (!alwaysOn && elapsed > maxRaspberryPiOnTime) {   // RPi never finished
            digitalWrite(RELAY_PIN, LOW);
            delay(5000);
            retry_count++;
            timerStart = getElapsedTime();
            Serial.print(F("RPi timeout, retry "));
            Serial.println(retry_count);
        }
        delay(20);                               // don't hot-spin (I2C is interrupt-driven)
    }
    if (retry_count >= 3) {
        digitalWrite(RELAY_PIN, LOW);
        Serial.println(F("Giving up until next slot"));
        applyPendingDigipot();
    }

    // anchor cadence to cycle START so RPi boot time doesn't stretch the lapse
    nextShotAt = cycleStart + intervalSeconds;
    unsigned long now = nowSeconds();
    if (nextShotAt <= now + 5) nextShotAt = now + 5;
    Serial.print(F("Next shot in "));
    Serial.print(nextShotAt - now);
    Serial.println(F(" s"));
}
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
void loop() {
    sampleSensors();                             // keep the I2C-readable cache fresh
    handleMinuteChange();

#if ENABLE_REED_TRIGGER
    reedState = digitalRead(REED_PIN);
    if (prevReedState == LOW && reedState == LOW && !reedConfirmedLow) {
        if (reedStabilityCounter > 0 && reedStabilityCounter < consecutiveReedValue)
            reedStabilityCounter++;
        if (reedStabilityCounter >= consecutiveReedValue) {
            reedConfirmedLow = true;
            reedStabilityCounter = 0;
        }
    } else {
        reedStabilityCounter = 0;
        reedConfirmedLow = false;
    }
    if (prevReedState == HIGH && reedState == LOW && reedHighCounter > consecutiveReedValue) {
        reedStabilityCounter = 1;
        reedConfirmedLow = false;
    }
    reedHighCounter = (reedState == HIGH) ? min(reedHighCounter + 1, 6) : 0;
#endif

    bool quiet = isTimeWithinRange(updateTimeStruct, ignoreTimeFrom, ignoreTimeTo);

    if (sendPing) {
        sendPing = false;
        initializationComplete = false;          // ping refreshes full config
        runCaptureCycle(TRIGGER_PING);
    } else if (!quiet && nowSeconds() >= nextShotAt) {
        runCaptureCycle(TRIGGER_TIMELAPSE);
    }
#if ENABLE_PIR_TRIGGER
    else if (!quiet) {
        pirState = digitalRead(PIR_PIN);
        if (pirState == HIGH && prevPirState == LOW)
            runCaptureCycle(TRIGGER_PIR);
        prevPirState = pirState;
    }
#endif
#if ENABLE_REED_TRIGGER
    else if (reedConfirmedLow) {
        reedConfirmedLow = false;
        runCaptureCycle(TRIGGER_REED);
    }
    prevReedState = reedState;
#endif

    // sleep until the next Timer2 tick (wakes ~61x/s, cheap enough)
    set_sleep_mode(SLEEP_MODE_PWR_SAVE);
    sleep_enable();
    sei();
    sleep_cpu();
    sleep_disable();
    cli();
    sei();
}

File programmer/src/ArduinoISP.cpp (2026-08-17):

// ArduinoISP
// Copyright (c) 2008-2011 Randall Bohn
// If you require a license, see
// https://opensource.org/licenses/bsd-license.php
//
// Note that this sketch refers to the SPI bus pins using the legacy MISO/MOSI
// names rather than the modern CIPO/COPI names.
// For further details, see https://docs.arduino.cc/learn/communication/spi
//
// This sketch turns the Arduino into a AVRISP using the following Arduino pins:
//
// Pin 10 is used to reset the target microcontroller.
//
// By default, the hardware SPI pins MISO, MOSI and SCK are used to communicate
// with the target. On all Arduinos, these pins can be found
// on the ICSP/SPI header:
//
//               MISO °. . 5V (!) Avoid this pin on Due, Zero...
//               SCK   . . MOSI
//                     . . GND
//
// On some Arduinos (Uno,...), pins MOSI, MISO and SCK are the same pins as
// digital pin 11, 12 and 13, respectively. That is why many tutorials instruct
// you to hook up the target to these pins. If you find this wiring more
// practical, have a define USE_OLD_STYLE_WIRING. This will work even when not
// using an Uno. (On an Uno this is not needed).
//
// Alternatively you can use any other digital pin by configuring
// software ('BitBanged') SPI and having appropriate defines for ARDUINOISP_PIN_MOSI,
// ARDUINOISP_PIN_MISO and ARDUINOISP_PIN_SCK.
//
// IMPORTANT: When using an Arduino that is not 5V tolerant (Due, Zero, ...) as
// the programmer, make sure to not expose any of the programmer's pins to 5V.
// A simple way to accomplish this is to power the complete system (programmer
// and target) at 3V3.
//
// Put an LED (with resistor) on the following pins:
// 9: Heartbeat   - shows the programmer is running
// 8: Error       - Lights up if something goes wrong (use red if that makes sense)
// 7: Programming - In communication with the target
//

#include "Arduino.h"
#undef SERIAL

// Forward declarations (the Arduino IDE auto-generates these for .ino files;
// as a plain .cpp under PlatformIO they must be explicit)
void heartbeat();
void reset_target(bool reset);
uint8_t getch();
void fill(int n);
void pulse(int pin, int times);
void prog_lamp(int state);
uint8_t spi_transaction(uint8_t a, uint8_t b, uint8_t c, uint8_t d);
void empty_reply();
void breply(uint8_t b);
void get_version(uint8_t c);
void set_parameters();
void start_pmode();
void end_pmode();
void universal();
void flash(uint8_t hilo, unsigned int addr, uint8_t data);
void commit(unsigned int addr);
void write_flash(int length);
uint8_t write_flash_pages(int length);
uint8_t write_eeprom(unsigned int length);
uint8_t write_eeprom_chunk(unsigned int start, unsigned int length);
void program_page();
uint8_t flash_read(uint8_t hilo, unsigned int addr);
char flash_read_page(int length);
char eeprom_read_page(int length);
void read_page();
void read_signature();
void avrisp();


#define PROG_FLICKER true

// Configure SPI clock (in Hz).
// E.g. for an ATtiny @ 128 kHz: the datasheet states that both the high and low
// SPI clock pulse must be > 2 CPU cycles, so take 3 cycles i.e. divide target
// f_cpu by 6:
//     #define SPI_CLOCK            (128000/6)
//
// A clock slow enough for an ATtiny85 @ 1 MHz, is a reasonable default:

#define SPI_CLOCK (1000000 / 6)


// Select hardware or software SPI, depending on SPI clock.
// Currently only for AVR, for other architectures (Due, Zero,...), hardware SPI
// is probably too fast anyway.

#if defined(ARDUINO_ARCH_AVR)

#if SPI_CLOCK > (F_CPU / 128)
#define USE_HARDWARE_SPI
#endif

#endif

// Configure which pins to use:

// The standard pin configuration.
#ifndef ARDUINO_HOODLOADER2

#define RESET 10  // Use pin 10 to reset the target rather than SS
#define LED_HB 9
#define LED_ERR 8
#define LED_PMODE 7

// Uncomment following line to use the old Uno style wiring
// (using pin 11, 12 and 13 instead of the SPI header) on Leonardo, Due...

// #define USE_OLD_STYLE_WIRING

#ifdef USE_OLD_STYLE_WIRING

#define ARDUINOISP_PIN_MOSI 11
#define ARDUINOISP_PIN_MISO 12
#define ARDUINOISP_PIN_SCK 13

#endif

// HOODLOADER2 means running sketches on the ATmega16U2 serial converter chips
// on Uno or Mega boards. We must use pins that are broken out:
#else

#define RESET 4
#define LED_HB 7
#define LED_ERR 6
#define LED_PMODE 5

#endif

// By default, use hardware SPI pins:
#ifndef ARDUINOISP_PIN_MOSI
#define ARDUINOISP_PIN_MOSI MOSI
#endif

#ifndef ARDUINOISP_PIN_MISO
#define ARDUINOISP_PIN_MISO MISO
#endif

#ifndef ARDUINOISP_PIN_SCK
#define ARDUINOISP_PIN_SCK SCK
#endif

// Force bitbanged SPI if not using the hardware SPI pins:
#if (ARDUINOISP_PIN_MISO != MISO) || (ARDUINOISP_PIN_MOSI != MOSI) || (ARDUINOISP_PIN_SCK != SCK)
#undef USE_HARDWARE_SPI
#endif


// Configure the serial port to use.
//
// Prefer the USB virtual serial port (aka. native USB port), if the Arduino has one:
//   - it does not autoreset (except for the magic baud rate of 1200).
//   - it is more reliable because of USB handshaking.
//
// Leonardo and similar have an USB virtual serial port: 'Serial'.
// Due and Zero have an USB virtual serial port: 'SerialUSB'.
//
// On the Due and Zero, 'Serial' can be used too, provided you disable autoreset.
// To use 'Serial': #define SERIAL Serial

#ifdef SERIAL_PORT_USBVIRTUAL
#define SERIAL SERIAL_PORT_USBVIRTUAL
#else
#define SERIAL Serial
#endif


// Configure the baud rate:

#define BAUDRATE 19200
// #define BAUDRATE	115200
// #define BAUDRATE	1000000


#define HWVER 2
#define SWMAJ 1
#define SWMIN 18

// STK Definitions
#define STK_OK 0x10
#define STK_FAILED 0x11
#define STK_UNKNOWN 0x12
#define STK_INSYNC 0x14
#define STK_NOSYNC 0x15
#define CRC_EOP 0x20  //ok it is a space...

void pulse(int pin, int times);

#ifdef USE_HARDWARE_SPI
#include "SPI.h"
#else

#define SPI_MODE0 0x00

#if !defined(ARDUINO_API_VERSION) || ARDUINO_API_VERSION != 10001  // A SPISettings class is declared by ArduinoCore-API 1.0.1
class SPISettings {
public:
  // clock is in Hz
  SPISettings(uint32_t clock, uint8_t bitOrder, uint8_t dataMode)
    : clockFreq(clock) {
    (void)bitOrder;
    (void)dataMode;
  };

  uint32_t getClockFreq() const {
    return clockFreq;
  }

private:
  uint32_t clockFreq;
};
#endif                                                             // !defined(ARDUINO_API_VERSION)
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

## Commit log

2026-08-17 Harden per code review: I2C-ISR hang fix, SD pruning, battery guard, uploader robustness, portability
    [burn_until_success.py, gh_uploader.py, main.cpp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]
2026-08-17 Add battery/telemetry to status.json + manifest + gallery; newest-first timelapse player
2026-08-17 Add ladybug enclosure part 1: parametric base tray + Lego-style stacking legs
    [ladybug_base.scad]
2026-08-17 Ladybug belly: FreeCAD parametric model, waterproof lift-off lid seal, Lego legs, verified STLs
    [belly.stl, foot.stl, ladybug.FCStd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]
2026-08-17 Belly fitted to real hardware: batwing IR board mounts under floor, V2/V3 camera lens-only hole
    [belly.stl, ladybug.FCStd]
2026-08-17 Exact IR-board geometry auto-extracted from IRarray-v6.1.pcbdoc: true 81x98.4 outline, real mount holes, VT90N1 sensor, JST pin ledge gaps
    [belly.stl, ladybug.FCStd, leg_segment.stl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]
2026-08-18 Part 2: domed elytra shell - matching labyrinth seal, 7 spots, eyes, M3 tabs; verified single solid
    [ladybug.FCStd, shell.stl]
2026-08-18 Flush IR board (seals its own opening), JST pin pockets, under-floor sheet frame, main trap-PCB standoffs from exact PcbDoc
    [belly.stl, ladybug.FCStd, shell.stl]
2026-08-18 Six legs (front/mid/rear pairs) at 20 deg splay - tuned against camera FOV; slimmer sheet frame
    [belly.stl, ladybug.FCStd]
2026-08-18 Open-hole design: no sheet, camera flush in pocket with housing cutout + FFC trench, legs back to 14 deg
    [belly.stl, ladybug.FCStd]
2026-08-18 Rectangular VT90N1 sensor window, camera cutout 11mm + flex-ribbon slot
    [belly.stl, ladybug.FCStd]
2026-08-18 Batwing recess for IR board + printed locating pins for both boards (no screws)
    [belly.stl, ladybug.FCStd]
2026-08-18 v6: per-column LED slots (exact positions), 13mm camera cutout moved up w/ L-flex slot, rigid 6x7 posts, battery-connector cradle, ball feet
    [belly.stl, foot.stl, ladybug.FCStd]
2026-08-18 Pogo-board slide-in bay over the camera (7.4mm seat spacing from Cam-Insert.3MF), camera up to y=36, trap PCB rides above on 9.5mm posts
    [belly.stl, ladybug.FCStd]
2026-08-18 Concept image: how the camera + pogo interface board stack works
2026-08-19 Sturdy leg system: round O17 blocks / O19 bosses / O20 ball feet with one standard 8mm square hole, 12mm straight pegs
    [belly.stl, foot.stl, ladybug.FCStd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]
2026-08-19 Proportional legs: O13 blocks / O16 bosses+feet, 7.0 peg in 7.6 rounded socket with 0.6 wiggle (also fits earlier 7.4-socket bellies)
    [belly.stl, foot.stl, ladybug.FCStd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]
2026-08-19 Leg fit tightened to 0.3mm wiggle (peg 7.15/socket 7.45); foot gets a boss-diameter collar so the joint reads continuous
    [belly.stl, foot.stl, ladybug.FCStd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]
2026-08-19 Shell tabs trimmed to the skirt line (collided with belly rebate wall); skirt drip gap 0.8mm for printed parts
    [ladybug.FCStd, shell.stl]
2026-08-19 Open-source the camera-trap hardware: IR array v5-v6.1, trap PCB (all generations + gerbers), PIR v1.0, full production 3D-part set
    [ATMEGA328P-AU-SMT2024.PcbDoc, ATMEGA328P-AU-SMT2024_N_N.PcbDoc, AntennaSafe.3MF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]
2026-08-19 Archive: BOMs, trap V3 schematic + pogo diagram, bring-up sketches, legacy Bitbucket camera code (credentials stripped)
    [AD_BOM_list.xlsx, Trap_v4_BOM.xls]
2026-08-19 Prune to reproduction essentials: drop Altium auto-backups, ECO logs, htm preview, prototype notes; fix cad/ path
2026-08-19 Enclosure v1.2: +20% floor area (142x188), hollow thin-wall shell, mounts unchanged
    [belly.stl, ladybug.FCStd, shell.stl]
2026-08-19 LAN admin on the Pi gallery: password-gated frame delete (un-bakes from video) + insect bbox editor; boxes flow to the public site
2026-08-19 Trail-camera footer: semi-transparent bar with timestamp + InsectDetect credit on every frame
2026-08-19 Gallery: friendly building-state before 8 video frames; hide 404 thumbs during cache transitions
2026-08-19 Ship BOTH enclosure sizes: stl/v1.1 (1:1 original) and stl/v1.2 (+20%), built in one run, shared legs
    [belly.stl, ladybug.FCStd, shell.stl]
2026-08-20 Timelapse plays NEWEST FIRST: frames reversed in segments, newest segment leads; player opens at the live edge
    [gh_uploader.py]
2026-08-20 Sun-position day/night gate + self-healing uploader
    - IR only when the sun is really below the horizon (NOAA solar elevation,
    lat/lon env-overridable): the LDR sits shaded under the belly and reads
    'night' in daylight, so it now only fine-tunes within the night window.
    - Re-assert Arduino always-on every cycle so an IR-surge brown-out reset
    can't cut the Pi's power.
    - Uploader rebuilds its work repo after 3 failed cycles (power cuts can
    corrupt the git object store).
    [gh_uploader.py, timelapse.py]
2026-08-20 Rename: Insect Detector -> Project Mariehøne
    "Mariehøne" is Danish for ladybug — which the enclosure literally is. Renamed
    to avoid colliding with the existing insect-detect project (Sittinger et al.).
    Repo slug: project-mariehoene (GitHub is ASCII-only). Firmware strings stay
    ASCII ("Mariehoene") for serial-monitor safety.
    [flash_next.py, gh_uploader.py, main.cpp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]
